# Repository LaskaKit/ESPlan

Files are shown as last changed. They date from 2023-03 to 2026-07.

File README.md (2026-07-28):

# ESPlan v2.1

**Read this in other languages: [Čeština](README_CZ)**

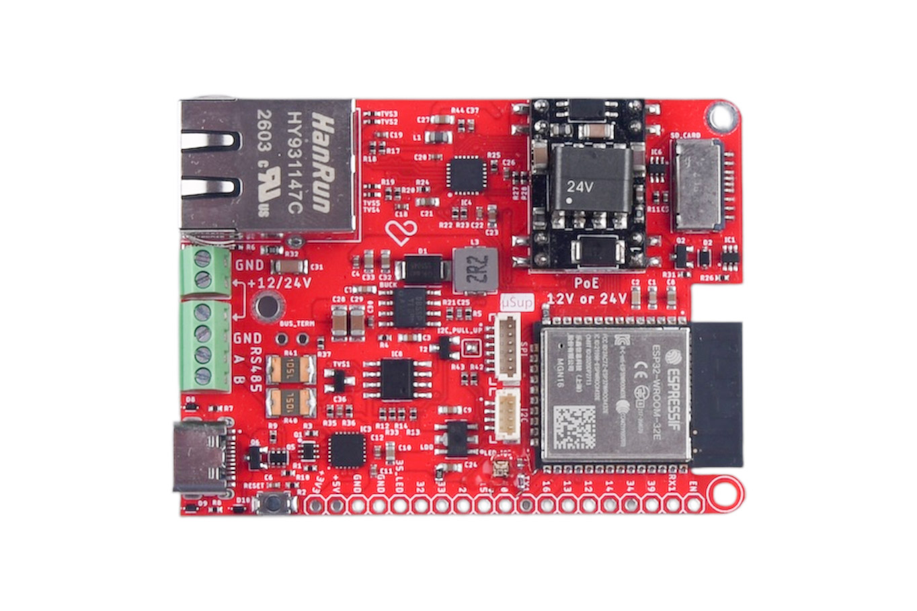
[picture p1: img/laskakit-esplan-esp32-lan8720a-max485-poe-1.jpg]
ESPlan


**LaskaKit ESPlan** is an industrial-grade ESP32 development board built around the **ESP32-WROOM-32E** module. It combines wired **Ethernet (LAN8720A)**, an **RS485** bus, **Wi-Fi + Bluetooth**, and **three independent ways to power the board** – including optional **PoE**. It is designed for industrial automation, IoT gateways, home automation (Home Assistant, ESPHome) and remote sensor nodes where reliable wired connectivity without dependence on Wi-Fi is required.

Designed and manufactured in the Czech Republic 🇨🇿

Product page: <https://www.laskakit.cz/laskakit-esplan-esp32-lan8720a-max485-poe/>

---

## ⚡ Power – three options

ESPlan v2.1 supports three power sources that can be combined freely. The source with the **highest voltage is always active**.

| Source | Input voltage | Path to the board | Typical use |
| --- | --- | --- | --- |
| **USB-C** | 5 V | direct to the 5 V rail | development, programming |
| **Screw terminal (+12/24 V, GND)** | **7–40 V DC** (12 or 24 V recommended) | step-down **LMR14050** (up to 5 A) → 5 V → LDO **XC6220** → 3.3 V | industrial PSU, DIN rail |
| **PoE (Power over Ethernet)** | via optional **SDaPo DP9900M** module (12 V or 24 V variant, **sold separately**) | PoE module output → same buck converter as the terminal | power straight from the LAN cable |

> **PoE note:** We recommend the **24 V** variant of the DP9900M – it better matches the converter input range and gives higher efficiency. The module meets **IEEE 802.3af** (up to 12.95 W), is galvanically isolated, and works with any PoE switch or injector.

The whole power chain is protected: terminal inputs are fused with a polyfuse, and the RS485 bus has TVS diodes (PSM712) and a polyfuse (MF-MSMF010-2) against overvoltage and shorts from the external line.

See annotated diagrams in [`img/power/`](img/power) for each option.

---

## 🔌 RS485 – wiring & terminal voltage

The RS485 terminal has **four pins: 12/24 V IN/OUT, GND, A, B**.

- **A and B are NOT power pins** – they carry the differential *data* signal from the **WS3081** transceiver. At idle the A−B difference is ~0 V; while transmitting, |A−B| is roughly **1.5–3 V** under load (per the RS485 standard the driver outputs ≥1.5 V differential, receivers detect ±200 mV, common-mode range −7 V to +12 V). **There is no usable supply voltage on A/B.**
- **Powering a remote RS485 device:** the terminal block also brings out **12/24 V IN/OUT**, so the same voltage you use to power the ESPlan (12 or 24 V) can be looped out to power a field sensor over the same run. If your sensor needs a different voltage (e.g. 5 V), use a local regulator at the sensor.
- **Bus wiring:** connect **A↔A, B↔B, GND↔GND**. At the end of a long run enable the on-board **120 Ω** termination with the **BUS_TERM** jumper – no external terminator needed.

---

## 🌐 Connectivity & interfaces

- **Ethernet** – LAN8720A PHY (Fast Ethernet 10/100 Mbps), HanRun RJ45 with integrated magnetics and status LEDs.
- **RS485** – WS3081 transceiver with TVS protection, screw terminal (12/24 V IN/OUT, GND, A, B), on-board 120 Ω termination via the `BUS_TERM` jumper.
- **Wi-Fi + Bluetooth** – built into the ESP32-WROOM-32E (2.4 GHz Wi-Fi 802.11 b/g/n, Bluetooth 4.2 / BLE).
- **microSD card** – slot over SPI with card-detect.
- **I²C connector** – dedicated 4-pin connector (3.3V, GND, SCL, SDA) with pull-ups for sensors, displays, etc.
- **SPI connector** – dedicated 6-pin connector (3.3V, GND, MOSI, MISO, SCK, CS).
- **GPIO header** – all free ESP32 pins broken out on a populated header.

---

## 📍 Pinout (v2.1)

| Function | GPIO |
| --- | --- |
| **I²C** SDA / SCL | IO33 / IO32 |
| **SPI** MISO / MOSI / CLK / CS | IO12 / IO13 / IO14 / IO15 |
| **microSD** MISO / MOSI / CLK / CS / CD | IO12 / IO13 / IO14 / IO2 / IO34 |
| **Ethernet** MDC / MDIO / NRST / CLK | IO23 / IO18 / IO5 / GPIO17 (out) |
| **User LED** (SK6812) | IO0 |
| Input-only pins | IO34, IO35, IO39 |

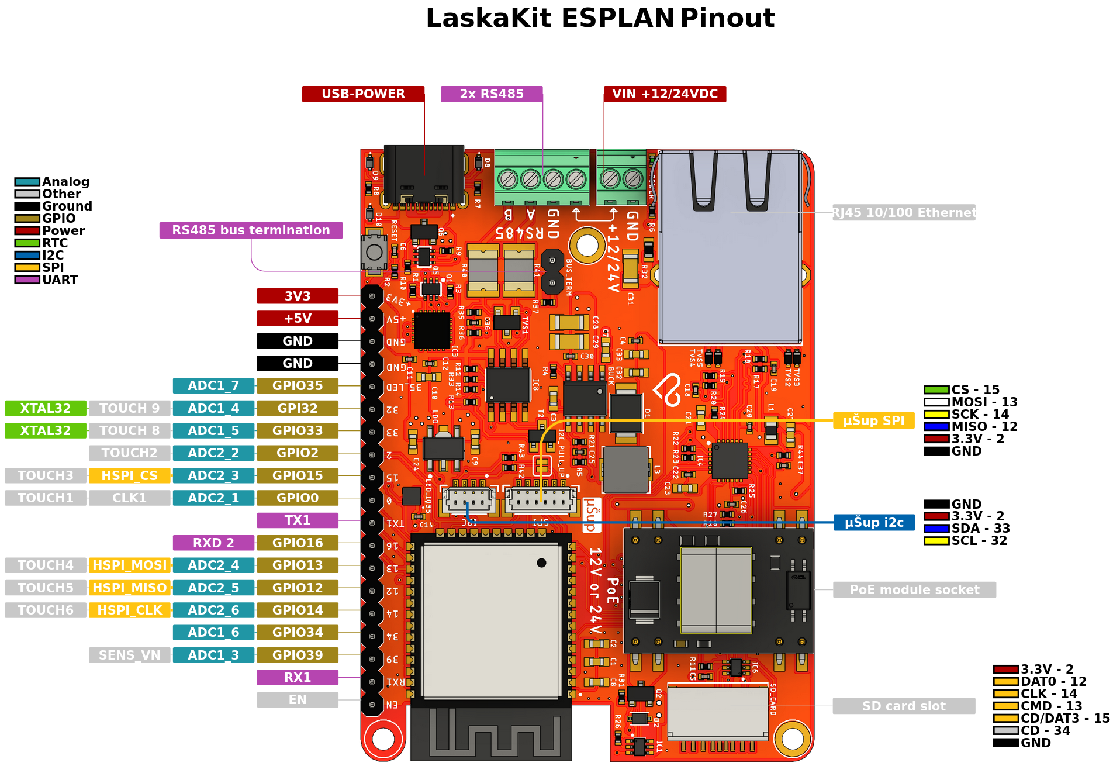
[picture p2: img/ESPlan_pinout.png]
ESPlan pinout


### Controls & LED

- **RESET** button – resets the ESP32.
- **IO0 / BOOT** button – enter firmware upload mode (RESET + IO0).
- **Status LED** (SK6812) on IO0 – programmable user LED.

> **Ethernet init (Arduino core 2.x):** the LAN8720A clock is on GPIO17. A known-good call is:
> ```cpp
> ETH.begin(0, -1, 23, 18, ETH_PHY_LAN8720, ETH_CLOCK_GPIO17_OUT);
> ```
> On newer cores use the named-enum signature, e.g. 
> ```cpp
> ETH.begin(ETH_PHY_LAN8720, ETH_ADDR, ETH_MDC_PIN, ETH_MDIO_PIN, ETH_POWER_PIN, ETH_CLOCK_GPIO17_OUT);
> ```
>
> **I²C init:**
> ```cpp
> Wire.begin(33, 32);
> ```
---

## 📐 Specifications

| | |
| --- | --- |
| **MCU** | ESP32-WROOM-32E (Xtensa LX6 dual-core 240 MHz, 4 MB Flash, Wi-Fi + BT) |
| **Ethernet PHY** | LAN8720A-CP, Fast Ethernet 10/100 Mbps |
| **RS485** | WS3081, half-duplex, TVS protection, optional 120 Ω termination |
| **Power – USB-C** | 5 V |
| **Power – terminal** | 7–40 V DC (12 or 24 V recommended) |
| **Power – PoE** | IEEE 802.3af via DP9900M module (12 V or 24 V variant, sold separately) |
| **Internal rails** | 5 V (buck LMR14050, up to 5 A) → 3.3 V (LDO XC6220) |
| **microSD** | SPI, connector with card detect |
| **Programming** | USB-C with on-board USB-UART bridge (auto-boot), RESET + BOOT buttons |
| **Compatibility** | Arduino IDE, ESP-IDF, ESPHome, Tasmota, MicroPython |

---

## 📦 Package contents

- 1× LaskaKit ESPlan v2.1

The PoE module (SDaPo DP9900M) and the 3D-printed enclosure are **not included** – ordered separately.

---

## 🖨️ 3D-printed enclosure

STL/3MF files for the enclosure are in the [`3D`](3D) folder.

---

## License & support

Open-source hardware by LaskaKit. Questions, issues and pull requests are welcome via the [Issues](../../issues) tab.

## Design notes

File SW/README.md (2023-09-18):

# How to make display work

1. Download [CH343SER.EXE](http://www.wch-ic.com/search?t=all&q=CH9102) and install it.

2. Connect ESPlan to your PC.

3. Open Device Manager (Start → Control Panel → Hardware and Sound → Device Manager) and find COM port number.

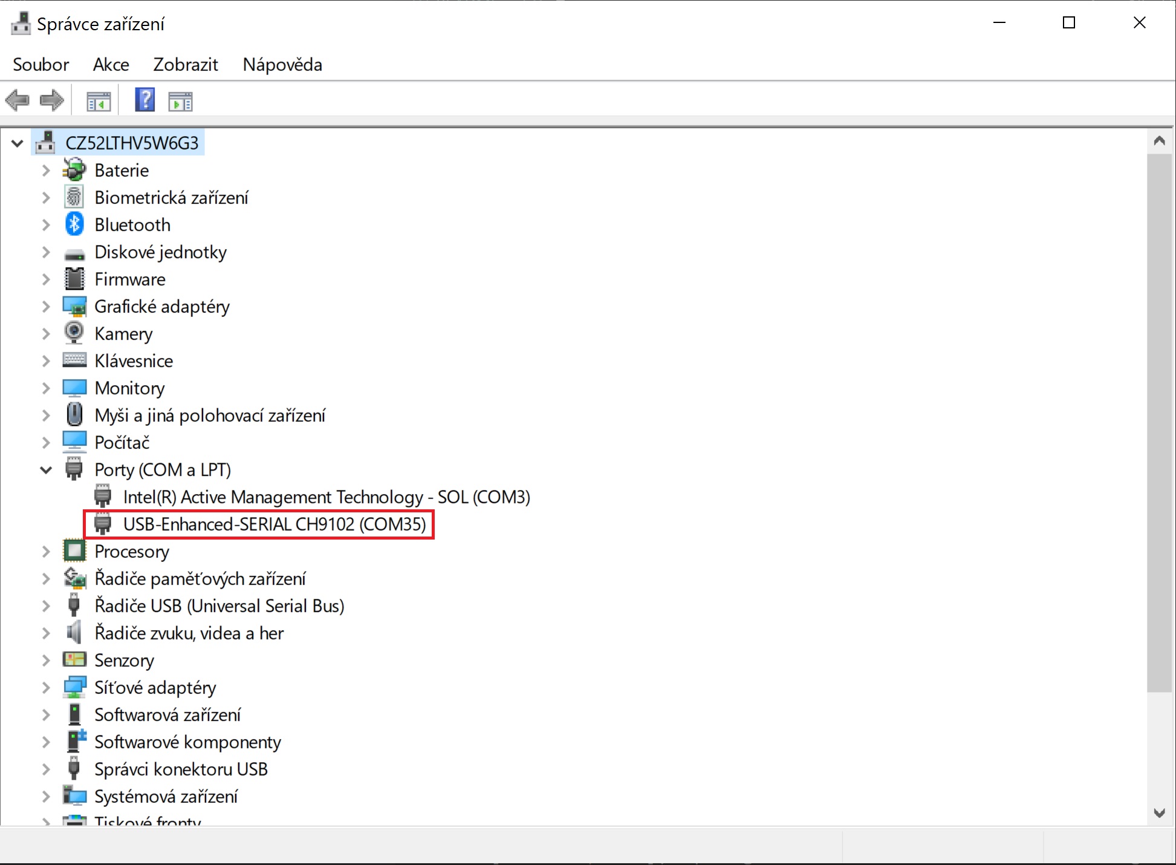
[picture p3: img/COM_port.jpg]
COM_port
    

## Arduino IDE
1. Download Github repository and look for project you want to try in [SW](../SW) folder.
2. Open example with Arduino IDE and set appropriate COM port and board type.
   
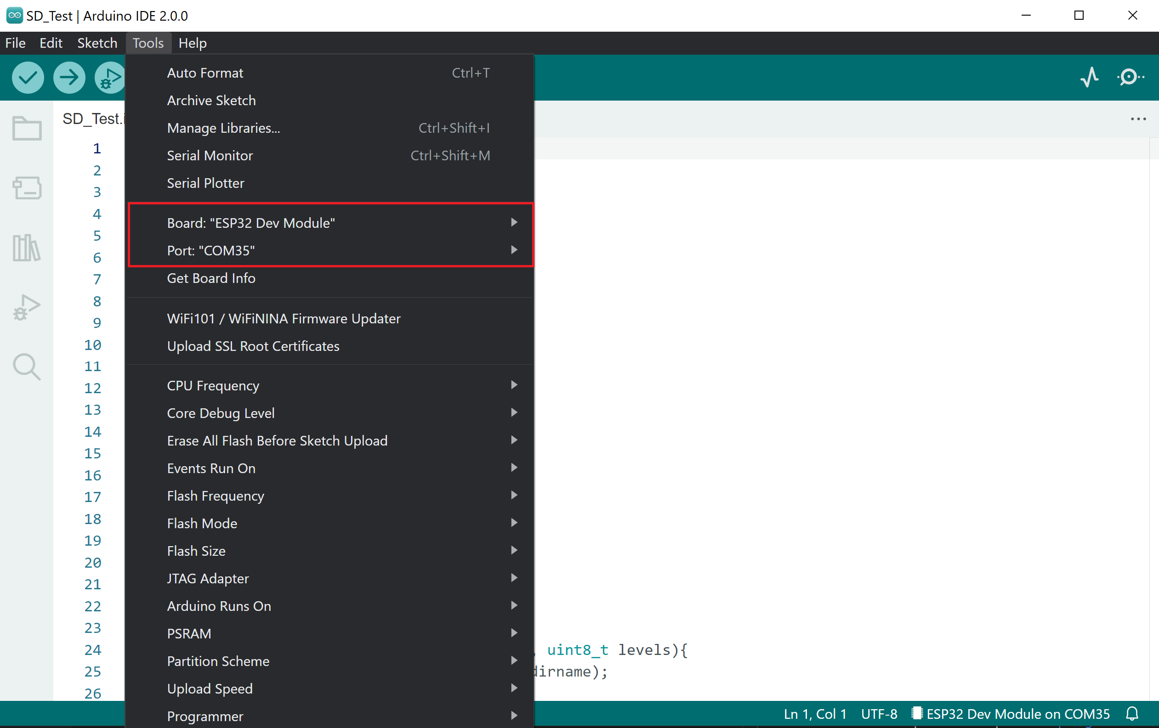
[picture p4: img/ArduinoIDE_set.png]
ArduinoIDE_set
    

3. Download necessary libraries.
4. Upload the code.

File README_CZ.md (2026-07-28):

# ESPlan v2.1

**Jiné jazyky: [English](README.md)**

ESPlan

**LaskaKit ESPlan** je průmyslová vývojová deska postavená na modulu **ESP32-WROOM-32E**. Kombinuje drátový **Ethernet (LAN8720A)**, sběrnici **RS485**, **Wi-Fi + Bluetooth** a **tři nezávislé způsoby napájení** – včetně volitelného **PoE**. Deska je určena pro průmyslovou automatizaci, IoT brány, domácí automatizaci (Home Assistant, ESPHome) i vzdálené senzorové uzly, kde je potřeba spolehlivá kabelová konektivita bez závislosti na Wi-Fi.

Navrženo a vyrobeno v ČR 🇨🇿

Stránka produktu: <https://www.laskakit.cz/laskakit-esplan-esp32-lan8720a-max485-poe/>

---

## ⚡ Napájení – tři možnosti

ESPlan v2.1 podporuje tři zdroje napájení, které lze libovolně kombinovat. Vždy je aktivní ten s **nejvyšším napětím**.

| Zdroj | Vstupní napětí | Cesta na desku | Typické použití |
| --- | --- | --- | --- |
| **USB-C** | 5 V | přímo na 5V větev | vývoj, programování |
| **Šroubovací svorkovnice (+12/24 V, GND)** | **7–40 V DC** (doporučeno 12 nebo 24 V) | step-down **LMR14050** (až 5 A) → 5 V → LDO **XC6220** → 3,3 V | průmyslový zdroj, DIN lišta |
| **PoE (Power over Ethernet)** | přes volitelný modul **SDaPo DP9900M** (varianta 12 V nebo 24 V, **kupuje se zvlášť**) | výstup PoE modulu → stejný buck měnič jako svorkovnice | napájení přímo z LAN kabelu |

> **Poznámka k PoE:** Doporučujeme variantu DP9900M **24 V** – lépe odpovídá vstupnímu rozsahu měniče a má vyšší účinnost. Modul splňuje **IEEE 802.3af** (až 12,95 W), má galvanické oddělení a pracuje s libovolným PoE switchem nebo injektorem.

Celý napájecí řetězec je chráněn: svorkovnicové vstupy jsou jištěny polyfuse, na RS485 sběrnici jsou TVS diody (PSM712) a polyfuse (MF-MSMF010-2) proti přepětí a zkratu z externího vedení.

Anotované obrázky ke každé možnosti najdeš v [`img/power/`](img/power).

---

## 🔌 RS485 – zapojení a napětí na svorkách

Svorkovnice RS485 má **tři vývody: GND, A, B**.

- **A a B nejsou napájecí piny** – nesou diferenciální *datový* signál z transceiveru **WS3081**. V klidu je rozdíl A−B přibližně 0 V; při vysílání je |A−B| zhruba **1,5–3 V** pod zátěží (dle standardu RS485 vysílač generuje ≥1,5 V diferenciálně, přijímač detekuje ±200 mV, common-mode rozsah −7 V až +12 V). **Žádné použitelné napájení na A/B není.**
- **Napájení připojeného RS485 zařízení:** na svorkovnici je navíc vyvedeno **12/24 V IN/OUT**, takže stejné napětí, kterým napájíš ESPlan (12 nebo 24 V), můžeš vyvést ven a napájet jím vzdálené čidlo po stejném vedení. Pokud čidlo potřebuje jiné napětí (např. 5 V), použij u čidla vlastní měnič.
- **Zapojení sběrnice:** propoj **A↔A, B↔B, GND↔GND**. Na konci dlouhého vedení zapni zakončovací odpor **120 Ω** jumperem **BUS_TERM** – externí terminátor není potřeba.

---

## 🌐 Konektivita a rozhraní

- **Ethernet** – PHY LAN8720A (Fast Ethernet 10/100 Mbps), konektor RJ45 HanRun s integrovanými transformátory a stavovými LED.
- **RS485** – transceiver WS3081 s TVS ochranou, šroubovací svorkovnice (GND, A, B), zakončení 120 Ω přes jumper `BUS_TERM`.
- **Wi-Fi + Bluetooth** – vestavěné v ESP32-WROOM-32E (2,4 GHz Wi-Fi 802.11 b/g/n, Bluetooth 4.2 / BLE).
- **microSD karta** – slot přes SPI s detekcí karty.
- **I²C konektor** – dedikovaný 4pinový konektor (3,3 V, GND, SCL, SDA) s pull-up rezistory pro senzory, displeje apod.
- **µSup konektor** – SPI konektor pro volitelný modul superkondenzátoru (µSup) pro krátké zálohování při výpadku napájení.
- **GPIO header** – všechny volné piny ESP32 vyvedeny na osazený header.

---

## 📍 Pinout (v2.1)

| Funkce | GPIO |
| --- | --- |
| **I²C** SDA / SCL | IO33 / IO32 |
| **SPI** MISO / MOSI / CLK / CS | IO12 / IO13 / IO14 / IO15 |
| **microSD** MISO / MOSI / CLK / CS / CD | IO12 / IO13 / IO14 / IO2 / IO34 |
| **Ethernet** MDC / MDIO / NRST / CLK | IO23 / IO18 / IO5 / GPIO17 (out) |
| **Uživatelská LED** (SK6812) | IO0 |
| Pouze vstupní piny | IO34, IO35, IO39 |

ESPlan pinout

### Ovládací prvky a LED

- Tlačítko **RESET** – reset ESP32.
- Tlačítko **IO0 / BOOT** – vstup do režimu nahrávání firmware (RESET + IO0).
- **Stavová LED** (SK6812) na IO0 – programovatelná uživatelská LED.

> **Inicializace Ethernetu (Arduino core 2.x):** hodiny LAN8720A jsou na GPIO17. Ověřené volání:
> ```cpp
> ETH.begin(0, -1, 23, 18, ETH_PHY_LAN8720, ETH_CLOCK_GPIO17_OUT);
> ```
> Na novějších core použij signaturu s pojmenovanými enumy, např. `ETH.begin(ETH_PHY_LAN8720, ETH_ADDR, ETH_MDC_PIN, ETH_MDIO_PIN, ETH_POWER_PIN, ETH_CLOCK_GPIO17_OUT);`
>
> **Inicializace I²C:** `Wire.begin(33, 32);`

---

## 📐 Specifikace

| | |
| --- | --- |
| **MCU** | ESP32-WROOM-32E (Xtensa LX6 dual-core 240 MHz, 4 MB Flash, Wi-Fi + BT) |
| **Ethernet PHY** | LAN8720A-CP, Fast Ethernet 10/100 Mbps |
| **RS485** | WS3081, half-duplex, TVS ochrana, volitelné zakončení 120 Ω |
| **Napájení – USB-C** | 5 V |
| **Napájení – svorkovnice** | 7–40 V DC (doporučeno 12 nebo 24 V) |
| **Napájení – PoE** | IEEE 802.3af přes modul DP9900M (varianta 12 V nebo 24 V, kupuje se zvlášť) |
| **Interní napájecí větve** | 5 V (buck LMR14050, až 5 A) → 3,3 V (LDO XC6220) |
| **microSD** | SPI, konektor s detekcí karty |
| **Programování** | USB-C s on-board USB-UART převodníkem (auto-boot), tlačítka RESET + BOOT |
| **Kompatibilita** | Arduino IDE, ESP-IDF, ESPHome, Tasmota, MicroPython |

---

## 📦 Obsah balení

- 1× LaskaKit ESPlan v2.1

PoE modul (SDaPo DP9900M) a 3D tištěná krabička **nejsou součástí balení** – objednávají se samostatně.

---

## 🖨️ 3D tištěná krabička

STL/3MF soubory krabičky najdeš ve složce [`3D`](3D).

---

## Licence a podpora

Open-source hardware od LaskaKit. Dotazy, chyby i pull requesty vítáme přes záložku [Issues](../../issues).

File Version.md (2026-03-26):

### Version 2.1
- LED IO changed from IO35 to IO0
- Added pull-down on IO12
#### Version 2.0
- Smaller board
- New power part, new PoE
- Power to RS485 from PoE
#### Version 1.1
- Added jumper for diskonecting CAN Bus 120Ihm resistor | Přidan jumper pro odpojení 120 Ohm odporu pro CAN sběrnici.
#### Version 1.0
- Initial | Počáteční

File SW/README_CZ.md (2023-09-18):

# Jak pracovat s displejem

1. Stáhnout [CH343SER.EXE](http://www.wch-ic.com/search?t=all&q=CH9102) a nainstalovat. Návod i na našem [blogu](https://blog.laskakit.cz/instalace-ovladace-prevodniku-usb-na-uart-ch340/).

2. Zapojit ESPlan do PC.

3. Start – Systém – Správce zařízení (může být potřeba oprávnění správce) najít položku Porty (COM a LPT).

    COM_port

## Arduino IDE
1. Stáhnout Github repository a otevřít příklad, který chcete zkusit ze složky [SW](../SW).
2. Otevřít příklad pomocí Arduino IDE a nastavit správný COM port a typ desky.
   
    ArduinoIDE_set

3. Stáhnout nezbytné knihovny.
4. Nahrát kód.

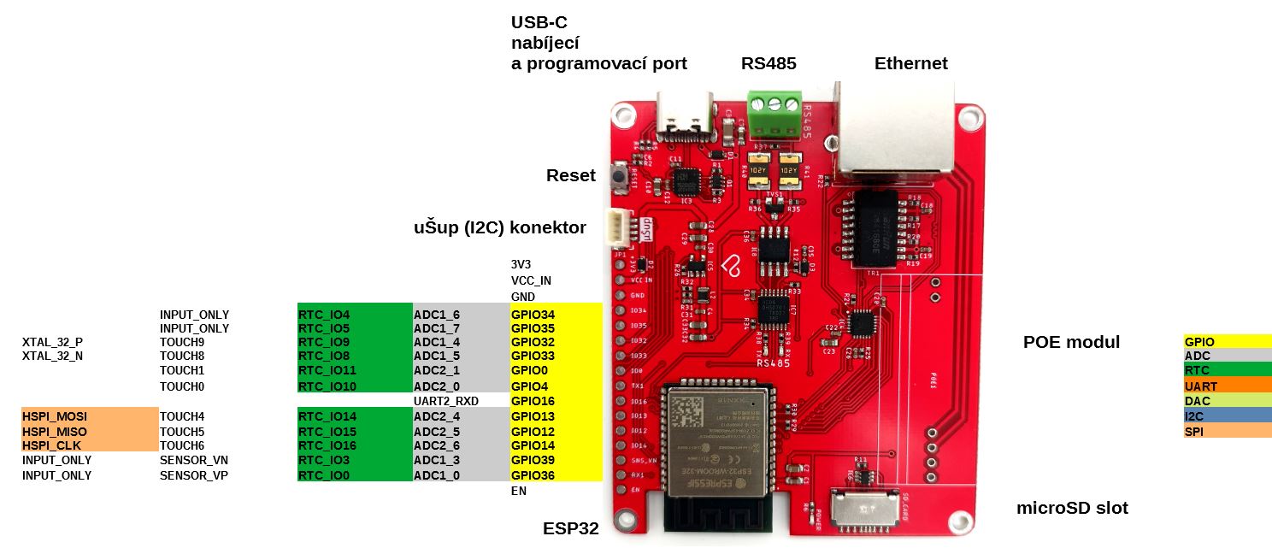
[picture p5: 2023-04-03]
img/ESPlan_pinout.JPG

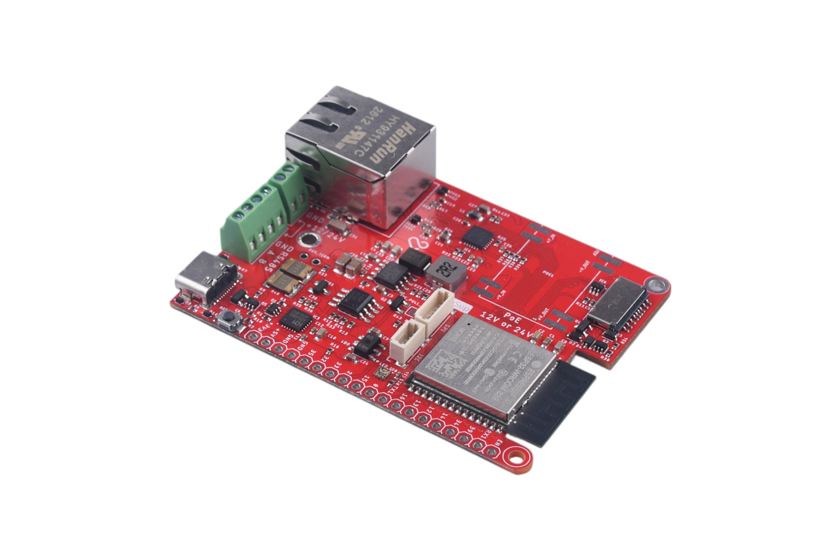
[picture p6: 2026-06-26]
img/laskakit-esplan-esp32-lan8720a-max485-3.jpg

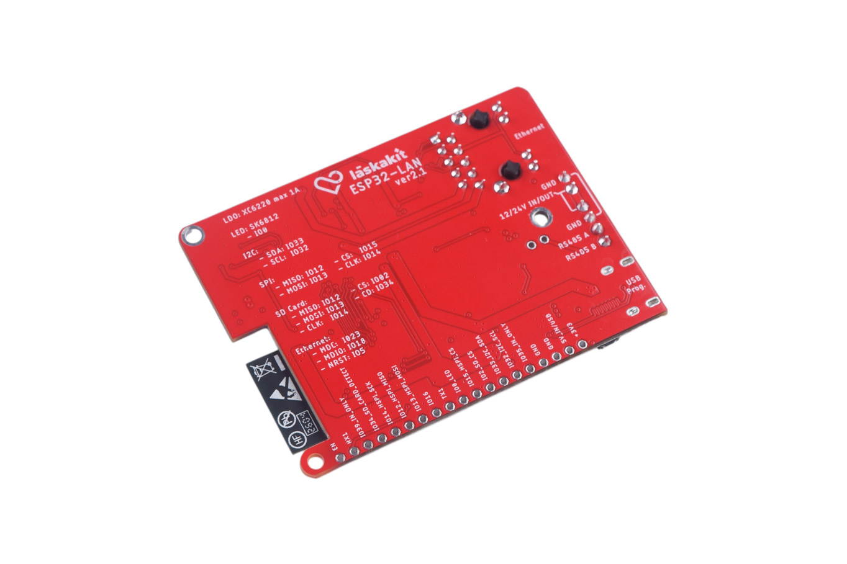
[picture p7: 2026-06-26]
img/laskakit-esplan-esp32-lan8720a-max485-poe-2.jpg

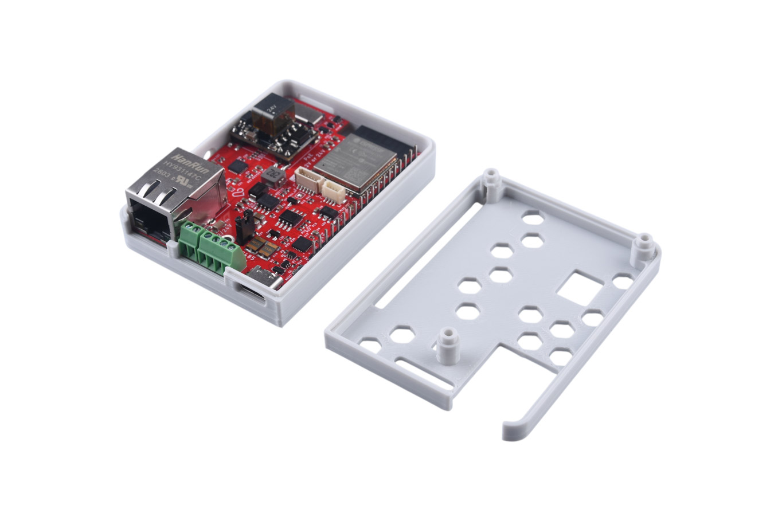
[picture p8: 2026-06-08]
img/laskakit-krabicka-pro-laskakit-esplan-v2-1.jpg

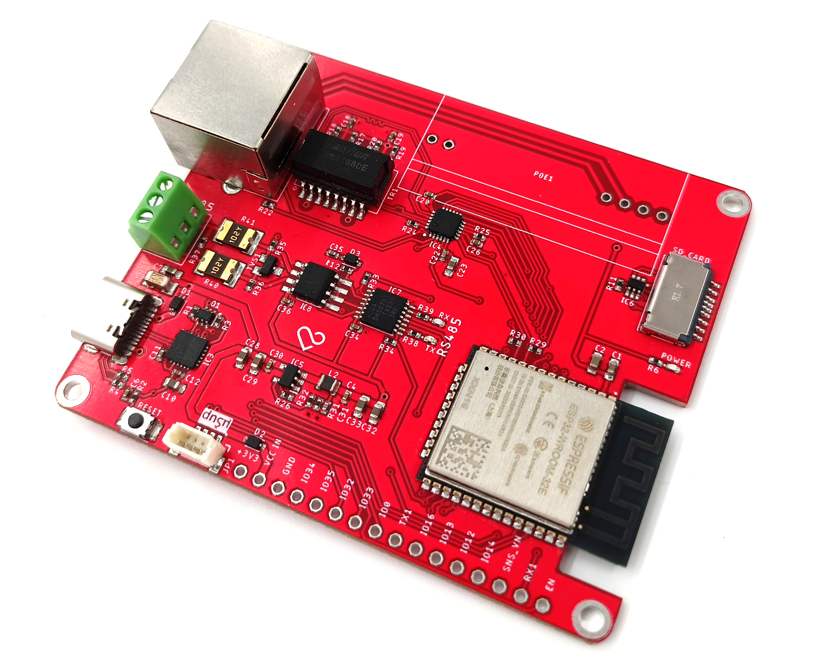
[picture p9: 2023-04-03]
img/ESPlan (2).jpg

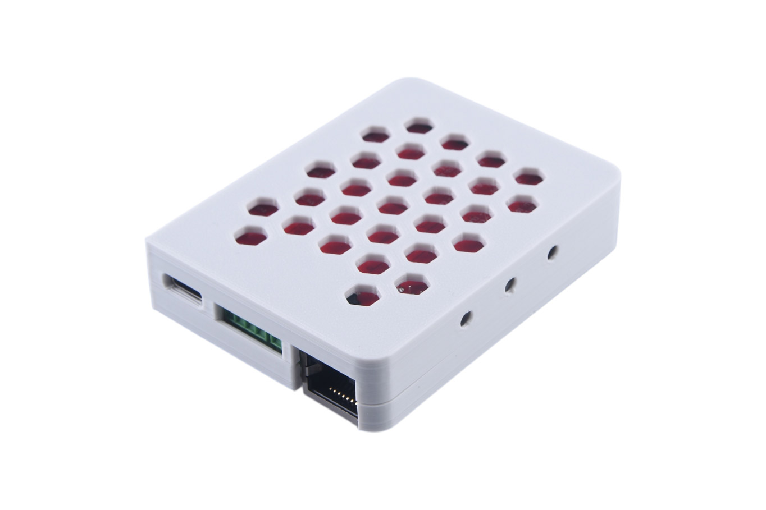
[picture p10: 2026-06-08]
img/laskakit-krabicka-pro-laskakit-esplan-v2-2.jpg

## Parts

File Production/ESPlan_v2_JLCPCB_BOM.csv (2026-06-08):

Comment | Designator | Footprint | LCSC Part #
100nF | C1 C7 | C0603
10k | R1 R2 R3 R11 R16 R25 R27 R28 R29 R30 R35 R36 R44 | R0402
100nF | C5 C6 C14 C36 C37 | C0402
TS1088R02026 | RESET | TS1088R02026 | C455280
MMDT3904 | Q1 | SC70-6 | C268586
47uF | C2 | C0603
uSup | J3 | 1X04_1MM_RA_VERT | C371588
ESP32-WROOM-32E | IC2 | ESP32WROOM32E | C701343
22uF | C8 C10 C27 C32 C33 | C0603
100n | C4 C11 C12 C18 C19 C20 C26 | C0402
CH9102F | IC3 | QFN24-4X4
LAN8720A-CP-ABC | IC4 | QFN50P400X400X100-25N | C510876
10uF | C21 | C0603
49.9 | R17 R18 R19 R20 | R0402
10n | C22 | C0402
2.2uF | C23 | C0603
YI201209U601-2R0T | L1 | L0805 | C2858468
1k | R22 R23 | R0402
12.1k | R24 | R0402
22uF/50V | C28 C29 | C1206 | C22367834
100n/50V | C30 | C0402
SMF05C | IC6 | SOT65P210X110-6N
WS3081 | IC8 | SO08 | C2691428
4.7k | R12 R13 R14 R33 R42 R43 | R0402
120 | R37 | R0402
PSM712-LF-T7 | TVS1 | SOT23 | C32677
MF-MSMF010-2 | R40 R41 | CT/CN1812 | C12430
2.4k | R6 | R0402
16-213/GHC-YR1S1/3T | POWER | CHIPLED_0402
TF-123-ARP9H17 | SD_CARD | SD_CARD_M | C2982548
TERMINAL_2_54_2P | T1 | TERMINAL_2_54_2P | C918120
10uF/16 | C9 | C0603
10uF/10V | C24 | C0603 | C19666
XC6220B331PR-G | LDO | XC6220B331PRG
5.1k | R7 R8 | R0402
USB-C_GT-USB-7010B | J2 | G-SWITCH_GT-USB-7010B | C2837092
LESD5D5.0CT1G | D8 D9 D10 | LESD5D50CT1G
MMDT5401 | Q3 Q5 | SC70-6 | C54540
DMG2305UX | Q6 | MICRO3 | C144153
47k | R9 R10 | R0402
USUP_SPI_CONNECTOR_VERT | J4 | 1X06_1MM_RA_VERT | C145963
2.2uH | L3 | L5.4X5.2 | C351096
LMR14050DDAR | BUCK | SO08-EPAD | C155484
20k | R4 | R0402
8.2nF | C3 | C0603
68k | R5 | R0402
12k | R21 | R0402
330pF | C25 | C0402
SS1045-SMB | D1 | SMB | C2903947
BZT52C15S | D2 | SOD323-R
0402WGF1004TCE | TVS2 TVS3 TVS4 TVS5 | SOD523 | C5185906
1n/2KV | C31 | C1206 | C23631
1M | R32 | R0603
HY931147C-RJ45 | J5 | HY931147C | C91754
S8050 | Q2 | SOT23-BEC
TERMINAL_2_54_4P | T3 | TERMINAL_2_54_4P | C918122
SK6812-EC20 | LED_IO0 | SK6812EC20
470 | R15 | R0402
SI2319 | Q4 | MICRO3 | C144153
100k | R34 R38 | R0402
1N4148 | D3 D4 | SOD323-R

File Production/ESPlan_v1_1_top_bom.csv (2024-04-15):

Comment | Designator | Footprint | LCSC Part #
1.1k | R32 | R0402
1N4148 | D3 | SOD323-R | C84063
1k | R22 | R0402
1uF | C7 | C0603
2.2uF | C23 | C0603
2.4k | R6 R38 R39 | R0402
4.7k | R33 R34 | R0402
4.99k | R31 | R0402 | C284594
5.1k | R4 R5 | R0402
10k | R1 R2 R3 R11 R25 R29 R30 R35 R36 | R0402
10n | C22 | C0402
12.1k | R24 | R0402
22p | C31 | C0402
22uF | C10 C28 C29 C32 C33 | C0603
33pF | C35 | C0402
47uF | C2 | C0603
49.9 | R17 R18 R19 R20 | R0402
56k | R12 | R0402
100k | R26 | R0402
100n | C4 C11 C12 C18 C19 C20 C26 C30 C34 | C0402
100nF | C1 | C0603
100nF | C6 C36 | C0402
100uF | C3 | C1206
120 | R37 | R0402
7404PW 118 | IC7 | TSSOP14 | C80000
BAT60B | D1 D2 D4 | SOD323-R
CH9102F | IC3 | QFN24-4X4
ESP32-WROOM-32E | IC2 | ESP32WROOM32E | C701343
GREEN | POWER RX | CHIPLED_0402
HR641680E | TR1 | ETH_TR
LAN8720A-CP-ABC | IC4 | QFN50P400X400X100-25N | C621419
MF-MSMF010-2 | R40 R41 | CT/CN1812 | C12430
MMDT3904 | Q1 | SC70-6 | C268586
MPL2016S2R2 | L2 | L2016 | C42215
ORANGE | TX | CHIPLED_0402
PSM712-LF-T7 | TVS1 | SOT23 | C32677
SMF05C | IC6 | SOT65P210X110-6N | C558425
SY8089AAAC | IC5 | SOT-23-5 | C78988
TF-123-ARP9H17 | SD_CARD | SD_CARD_M | C2982548
TS1088R02026 | RESET | TS1088R02026 | C455280
USB-C_2-16PIN | J4 | USBC_USB-C-16P-5 | C2837092
WS3081 | IC8 | SO08 | C2691428
uSup | J3 | 1X04_1MM_RA_VERT | C371588
1k | R23 | R0402
1n/2KV | C15 | C1206 | C23631
10k | R27 R28 R42 R43 | R0402
10n/100V | C13 C14 C16 C17 | C0603
10uF | C21 | C0603
22uF | C27 | C0603
75 | R13 R14 R15 R16 | R0603 | C112309
100nF | C5 | C0402
YI201209U601-2R0T | L1 | L0805 | C2858468
TERMINAL_2_54_3P | RS485 | TERMINAL_2_54_3P | C68305
R-RJ45R08P-C000 | LAN | R-RJ45R08P-C000 | C386757

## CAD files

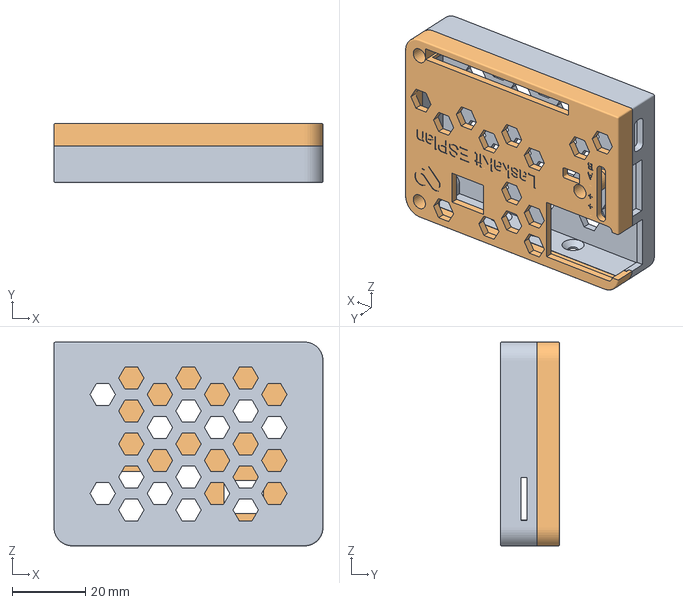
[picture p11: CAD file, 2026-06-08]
3D/ESPlan_case_V2.3mf
73.4 x 16.2 x 55.6 mm

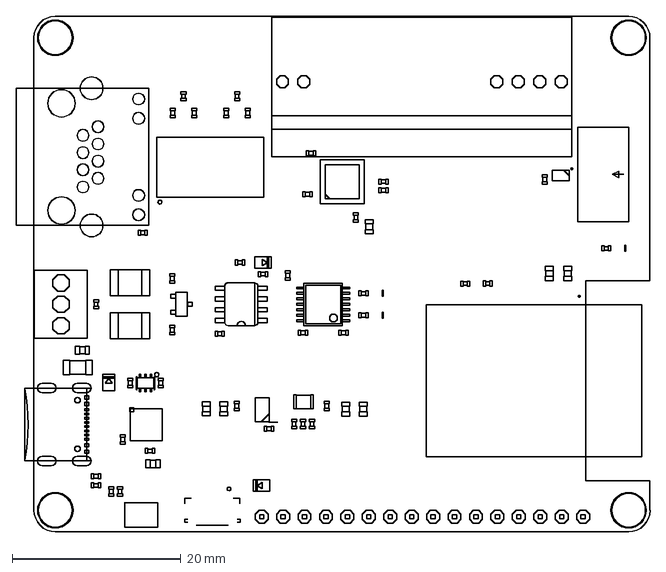
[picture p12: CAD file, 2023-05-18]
HW/ESPlan v1.dxf
75.1 x 61.1 mm

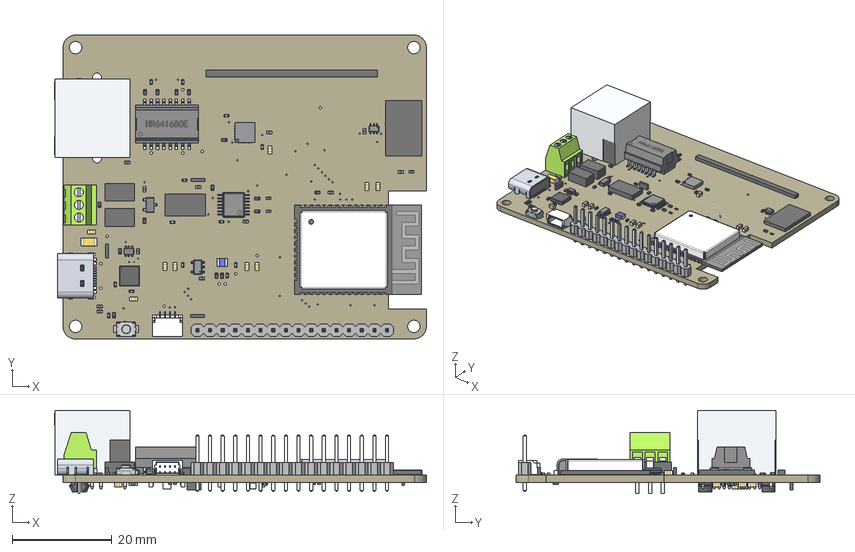
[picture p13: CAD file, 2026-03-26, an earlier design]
3D/old/ESPlan.step
74.7 x 61.1 x 16.7 mm
Board
Gehäuse
Kontaktfläche x 2
LASKAKIT_HEART_4MM
USUP_4MM_SILKSCREEN
1X04_1MM_RA
1X16
USBC_USB-C-16P-5
SC70-6
SOT23
QFN24-4X4
ThermalPin
PinsArrayLR
PinsArrayTB
PinsArrayLR (1)
TSSOP14
DP1435
PinsArrayL
PinsArrayR
TS1088R02026
SO08
ETH_TR
term1
term2
RJ45_LED
SD_CARD_M
Housing
PlasticBody
ESP32WROOM32E
Pin1 x 15
Pin2 x 15
CeramicBody x 15
CHIPLED_0402 x 3
2,5-PAD x 4
SOD323-R x 4
C0603 x 15
C1206 x 2
R0402 x 32
R0603 x 4
CT/CN1812 x 2

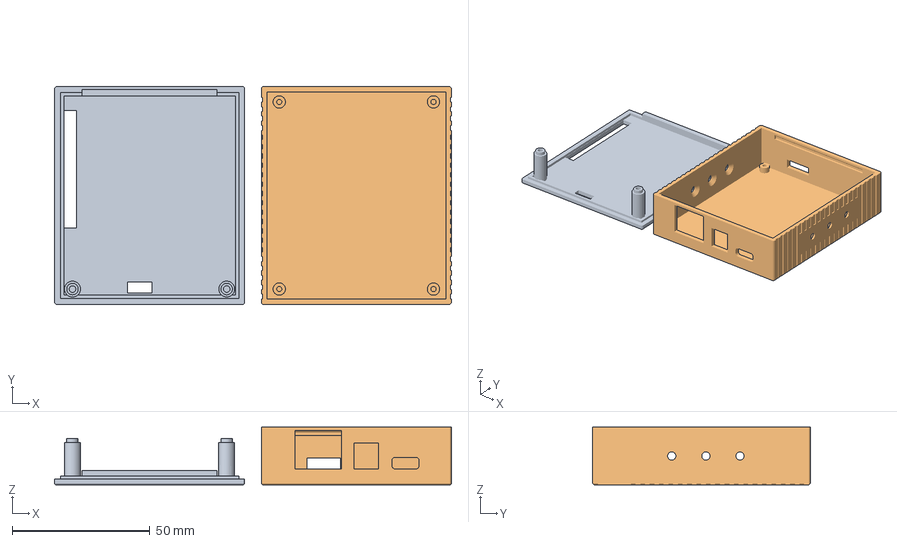
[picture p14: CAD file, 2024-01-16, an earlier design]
3D/ESPlan_case.3mf
144.2 x 79.0 x 21.0 mm
Bottom_cover v12
Top_cover

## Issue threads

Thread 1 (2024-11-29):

Ethernet not getting IP adress - ESPlan nedostavá ip adresu

ondrej1808, 2024-11-29:
Dobrý den,

mám problém s Ethernetem na desce ESPlan 1.1:

Měl jsem na novém ESPlan 1.1 jednoduchý program, který četl digitální vstupy a ty zobrazoval na modbus serveru.
Po určité době vývoje tohoto projektu se při nahrání nového kódu stane, že přestane dostavát ip adresu.
Resp.: když si do sériového výstupu vypíšu ip adresu tak dostanu 0.0.0.0, což znamená, že buďto neproběhla
žádná komunikace s routerem nebo ESPlan ani o adresu nezažádalo.

Zkoušel jsem použít novou desku, ta však zhruba po měsíci, když jsem pouze odpojil a připojil síťový kabel, tak začala vykazovat stejný problém.

Dále jsem zkoušel jednoduchý kód, který se má připojit k síti a vypsat ip adresu, opět neúspěšně.
Nemyslím si že by byl problém na straně routeru a nastevní sítě, jelikož úplně nová deska fungovala s posledním kódem staré desky.

Testovací kód pro připojení k WiFi (PlatformIO, framework arduino):

main.cpp:
```
#include <Arduino.h>
#include <ETH.h>
#include <WiFi.h>

#define ETH_POWER_PIN -1
#define ETH_ADDR 0
#define ETH_MDC_PIN 23
#define ETH_MDIO_PIN 18
#define ETH_NRST_PIN 5

bool eth_connected = false;

void WiFiEvent(WiFiEvent_t event)
{
  switch (event)
  {
  case ARDUINO_EVENT_ETH_START:
    Serial.println("ETH Started");
    // set eth hostname here
    ETH.setHostname("UCS2.0");
    break;
  case ARDUINO_EVENT_ETH_CONNECTED:
    Serial.println("ETH Connected");
    break;
  case ARDUINO_EVENT_ETH_GOT_IP:
    Serial.print("ETH MAC: ");
    Serial.print(ETH.macAddress());
    Serial.print(", IPv4: ");
    Serial.print(ETH.localIP());
    if (ETH.fullDuplex())
    {
      Serial.print(", FULL_DUPLEX");
    }
    Serial.print(", ");
    Serial.print(ETH.linkSpeed());
    Serial.println("Mbps");
    eth_connected = true;
    break;
  case ARDUINO_EVENT_ETH_DISCONNECTED:
    Serial.println("ETH Disconnected");
    eth_connected = false;
    break;
  case ARDUINO_EVENT_ETH_STOP:
    Serial.println("ETH Stopped");
    eth_connected = false;
    break;
  default:
    break;
  }
}

void setup()
{
  Serial.begin(115200);
  // For reseting LAN8720A
  pinMode(ETH_NRST_PIN, OUTPUT);
  digitalWrite(ETH_NRST_PIN, LOW);
  delay(500);
  digitalWrite(ETH_NRST_PIN, HIGH);

  WiFi.onEvent(WiFiEvent);

  ETH.begin(ETH_ADDR, ETH_POWER_PIN, ETH_MDC_PIN, ETH_MDIO_PIN, ETH_PHY_LAN8720, ETH_CLOCK_GPIO17_OUT);

  delay(2000);
  Serial.println("Ethernet status: " + ETH.localIP().toString() + " " + ETH.macAddress() + " " + ETH.linkSpeed() + "Mbps");
}

void loop()
{
  // put your main code here, to run repeatedly:
}
```

platformio.ini:
```
[env:esp32dev]
platform = espressif32
board = esp32dev
framework = arduino
monitor_speed = 115200
```

Výstup v sériovém monitoru:
```
rst:0xc (SW_CPU_RESET),boot:0x17 (SPI_FAST_FLASH_BOOT)
configsip: 0, SPIWP:0xee
clk_drv:0x00,q_drv:0x00,d_drv:0x00,cs0_drv:0x00,hd_drv:0x00,wp_drv:0x00
mode:DIO, clock div:2
load:0x3fff0030,len:1184
load:0x40078000,len:13232
load:0x40080400,len:3028
entry 0x400805e4
0
ETH Started
Ethernet status: 0.0.0.0 70:B8:F6:4C:62:53 10Mbps
ets Jul 29 2019 12:21:46
```

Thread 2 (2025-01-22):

3D files fail to load using Prusa Slicer

hamanbnl, 2025-01-22:
As described in the topic.
Prusa Slicer: Version 2.8.1+win64

Step file : "Invalid string position".
Unfortunately - nothing more.

3mf file: PrusaSlicer has encountered an error "Loading of a model file failed".
No details more.

Please correct the above files or post STL or OBJ files in right shape for importing.
Thanks in advance

hamanbnl, 2025-01-22:
Dobry večer,

Typická arogantní odpověď : “Pro mně funguje”.
Napsal jsem van verze, a tam je vidět, že používám windows. A ne Mac.
Ne napsali jste jakou verzi programu užíváte.

Ja mam problém a ne vy i prosím o vyřešení, protože jsem jisty ze nejsem
sám s tym problémem.

S pozdravem
Emil Krotki
+420 731 051 269

On Wed 22. 1. 2025 at 11:09, Konstantin Láska ***@***.***>
wrote:

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

Konstantin-G, 2025-01-22:
Dobrý den,
verze jsem napsal: 2.9.0.
na windows vám kolega psal, že zkoušel:
Dobrý den, soubory jsou v pořádku. Vyzkoušel jsem aktuální verzi souboru a v Prusa sliceru jsem jej bez problémů otevřel. Je spíše možné, že se soubor chybně stáhnul. Zkuste stáhnout celý projekt jako zip.

hamanbnl, 2025-01-22:
Dobry večer,

Našel jsem kde je problém. Odkaz ze stránek obchodu vede k GitHub. Tam jsou
dva soubory, stažení jejich rovné “save as” vede k chybě.

Je nezbytné využít “download raw file”. Tenhle funguje správně, ověřil jsem
na “3mf” a to pro mě stačí.
Dal bych na stránkách varováni pro lamerů jako ja.

Bohužel, mam už svůj projekt, ještě možna využiji vaši krytku, ale nezbytné
to není, uděláni krytky je 15 minut, no možná 30…

Doporučoval bych také tisk s využitím nehořlavého filamentu, ale to
zvládnu, a na stánkách obchodu varoval bych lidi o tom.

Moc dekuji, přeji hezký večer.

S pozdravem
Emil Krotki
+420 731 051 269

On Wed 22. 1. 2025 at 19:21, Konstantin Láska ***@***.***>
wrote:

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

Closed 2025-01-22.

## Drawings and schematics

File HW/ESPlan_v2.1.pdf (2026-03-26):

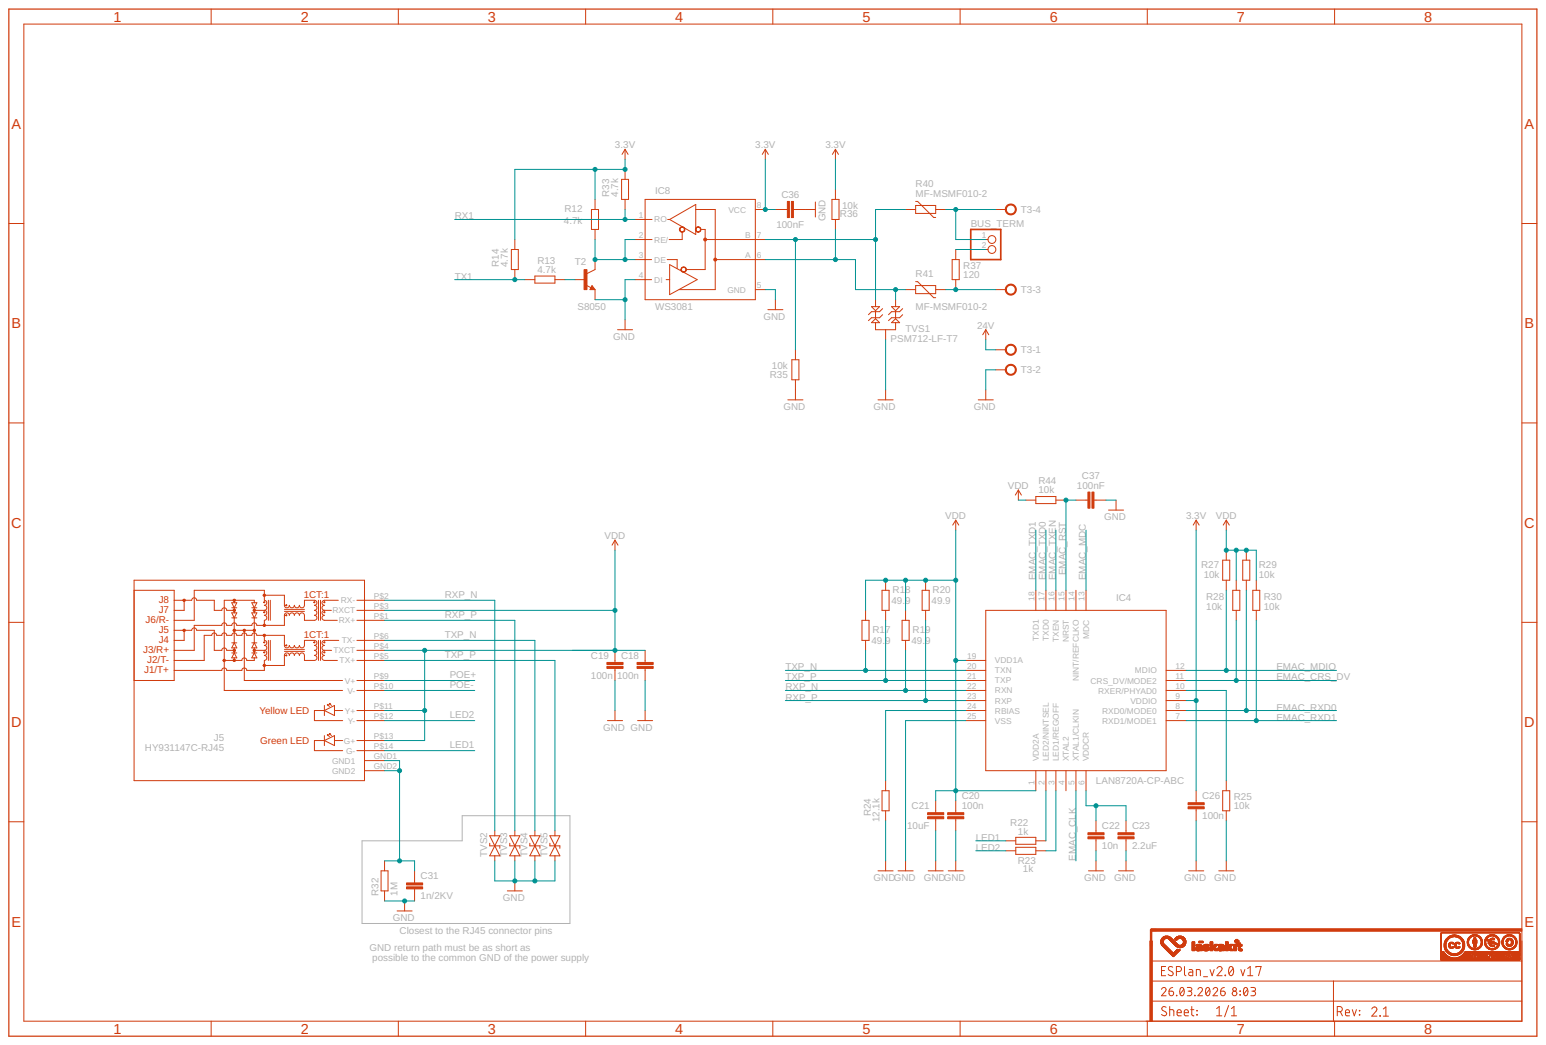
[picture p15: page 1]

GND
Closest to the RJ45 connector pins GND return path must be as short as possible to the common GND of the power supply

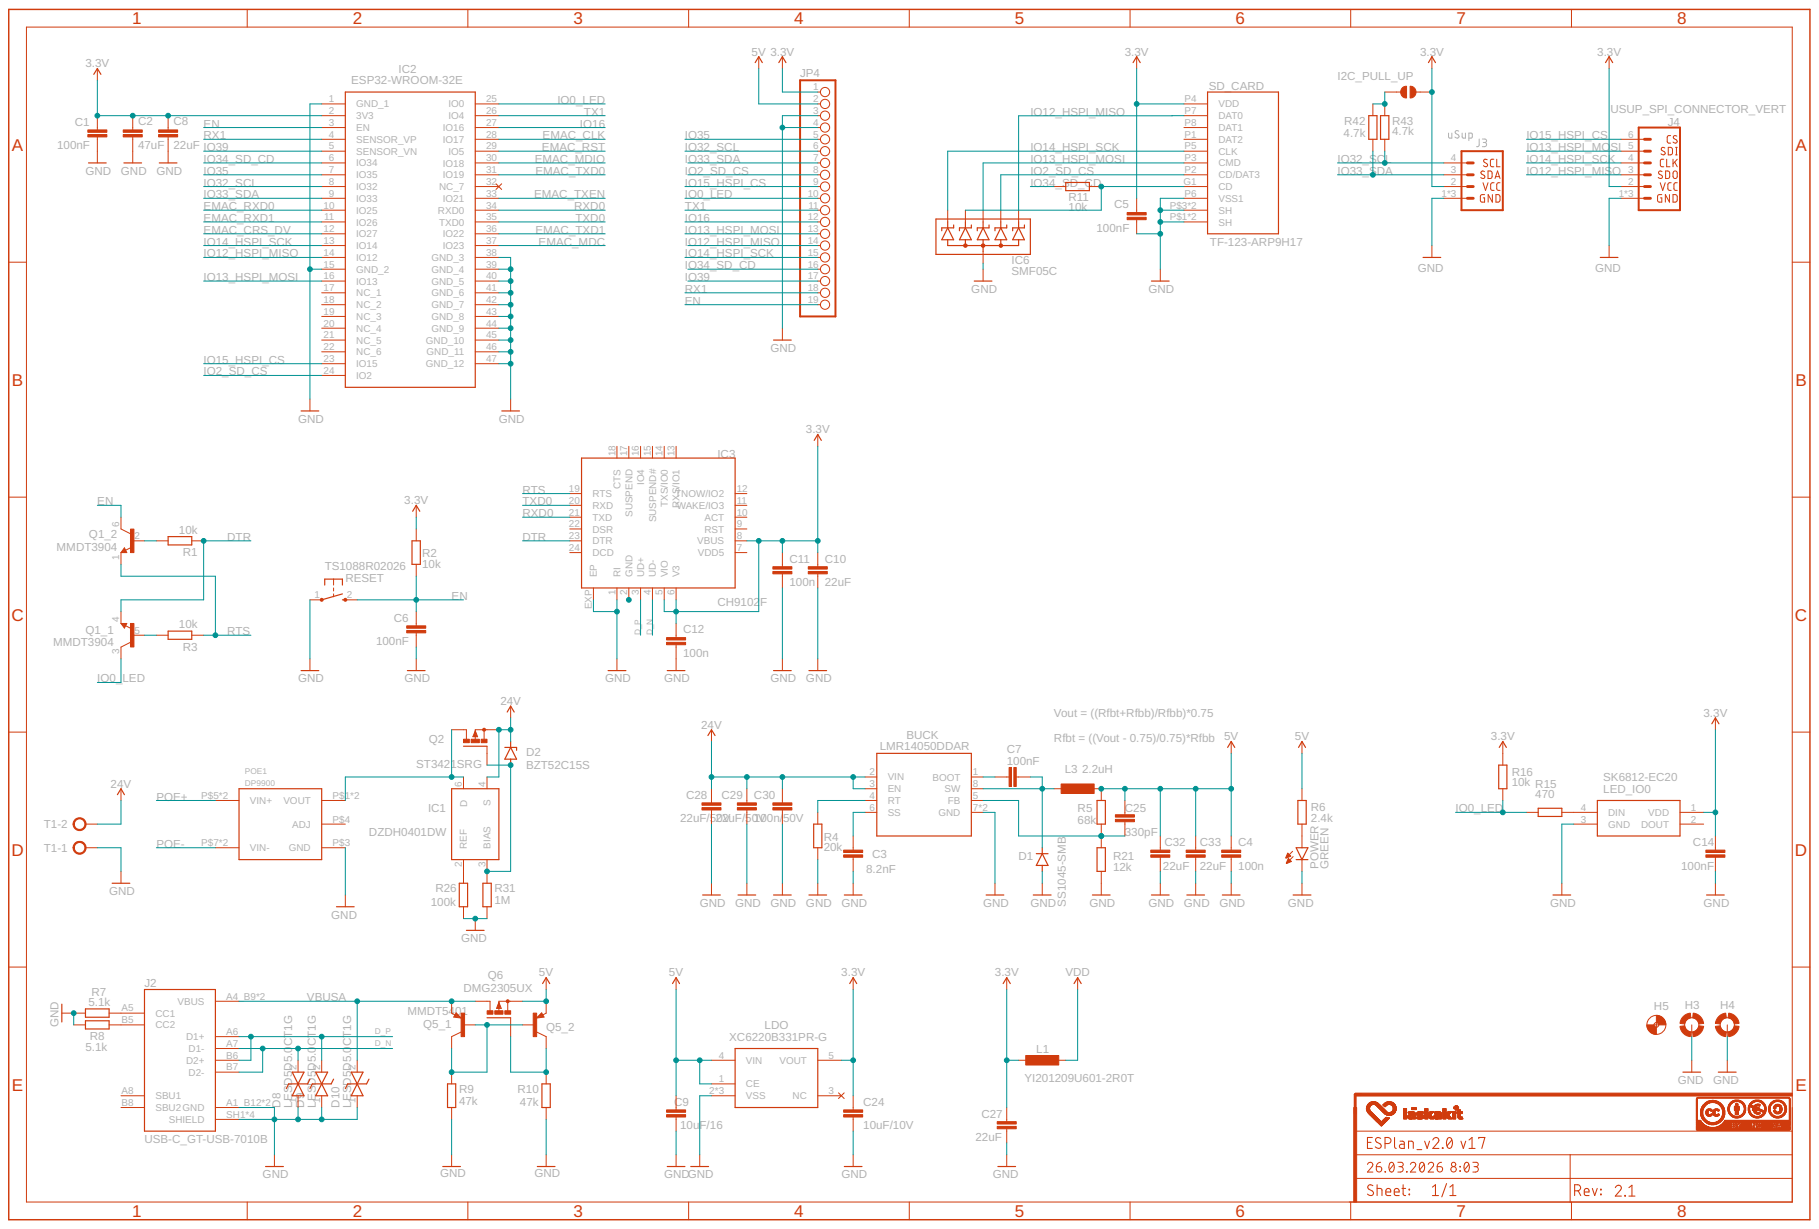
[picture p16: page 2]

Vout = ((Rfbt+Rfbb)/Rfbb)*0.75 Rfbt = ((Vout - 0.75)/0.75)*Rfbb

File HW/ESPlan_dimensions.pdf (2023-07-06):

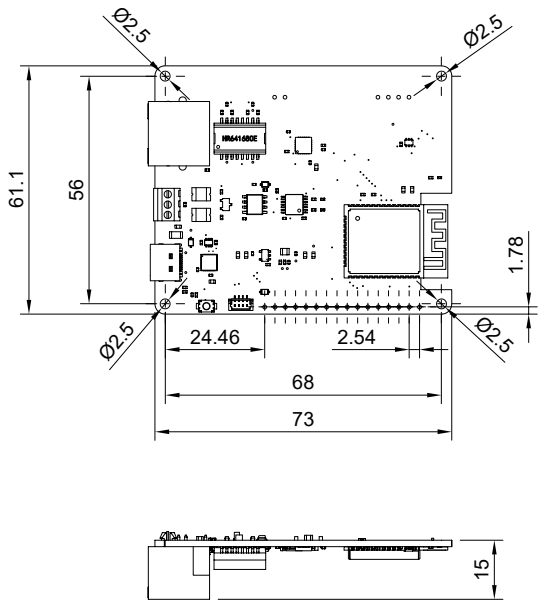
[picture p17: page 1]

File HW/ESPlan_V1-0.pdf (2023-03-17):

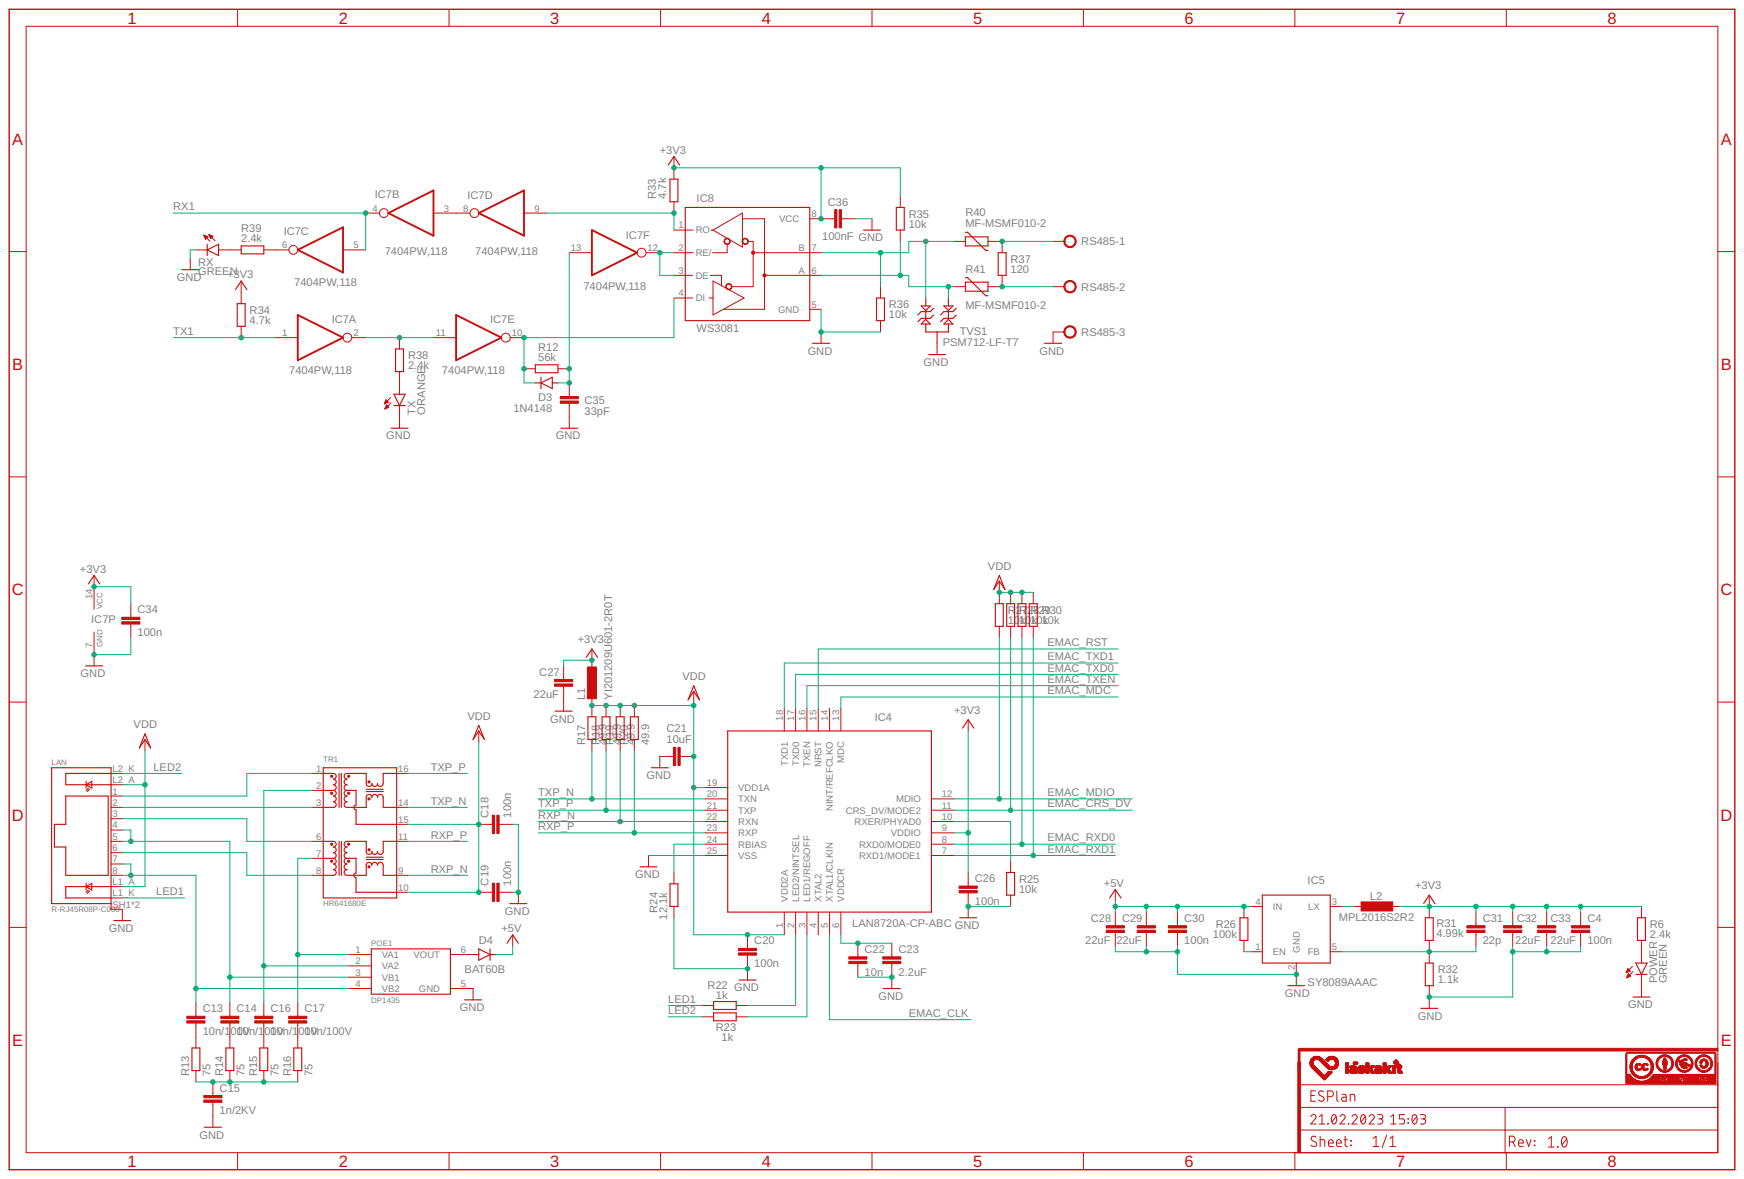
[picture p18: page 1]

EMAC_TXD1
EMAC_TXD0
EMAC_TXEN
EMAC_MDC

IC4 | EMAC_MDIO EMAC_CRS_DV EMAC_RXD0

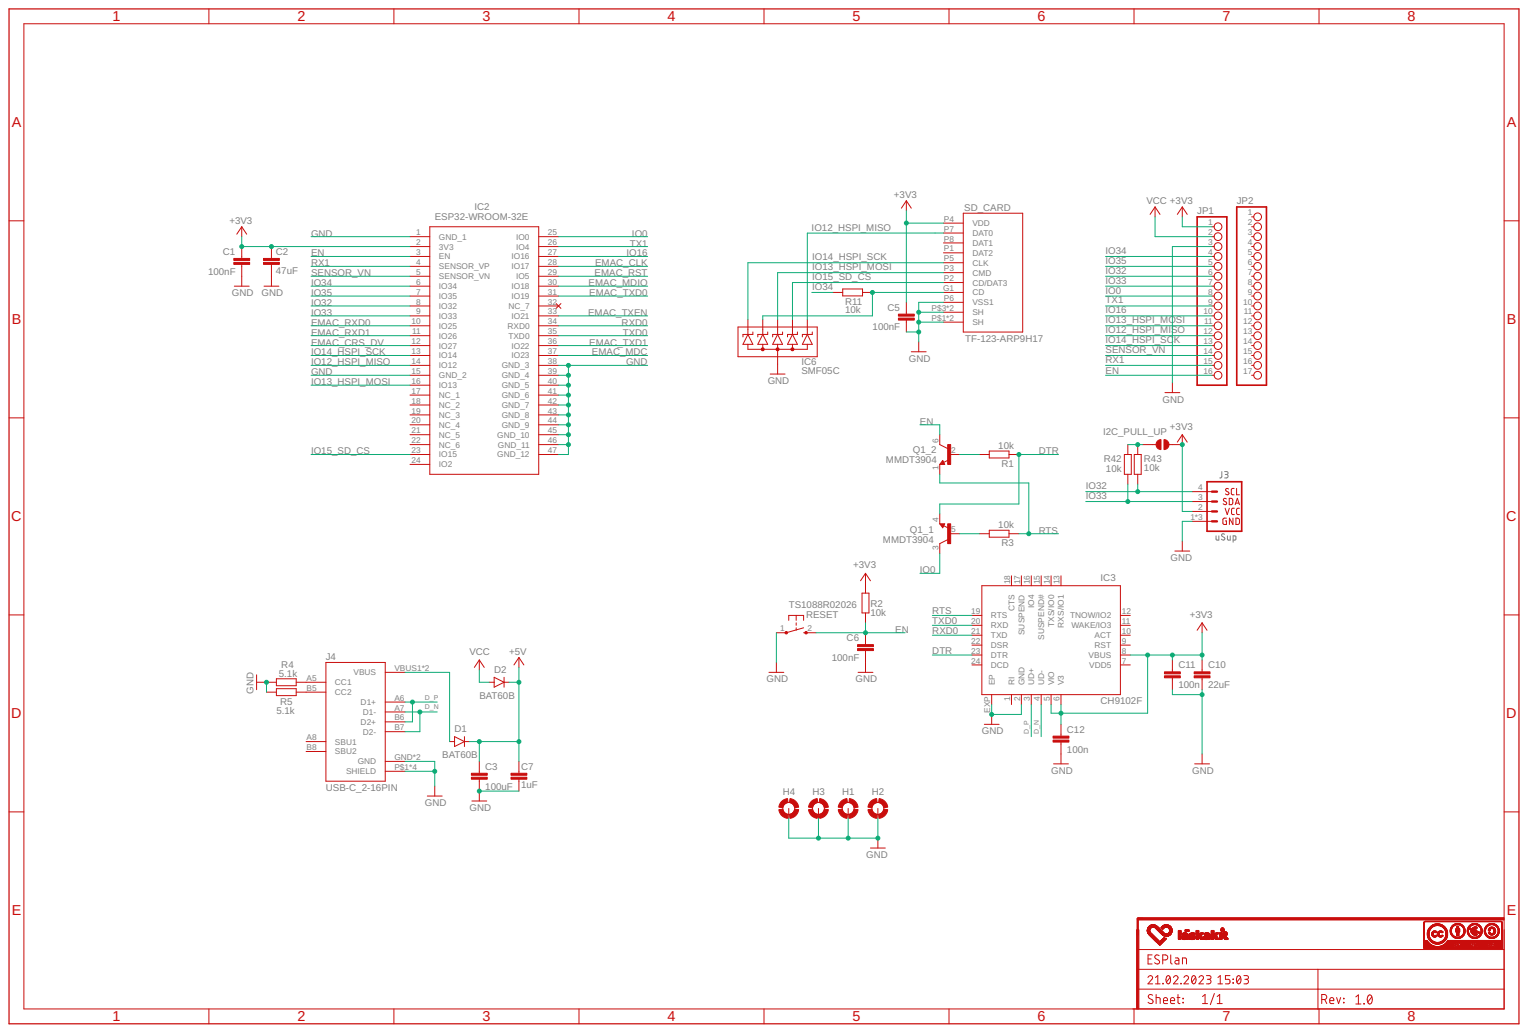
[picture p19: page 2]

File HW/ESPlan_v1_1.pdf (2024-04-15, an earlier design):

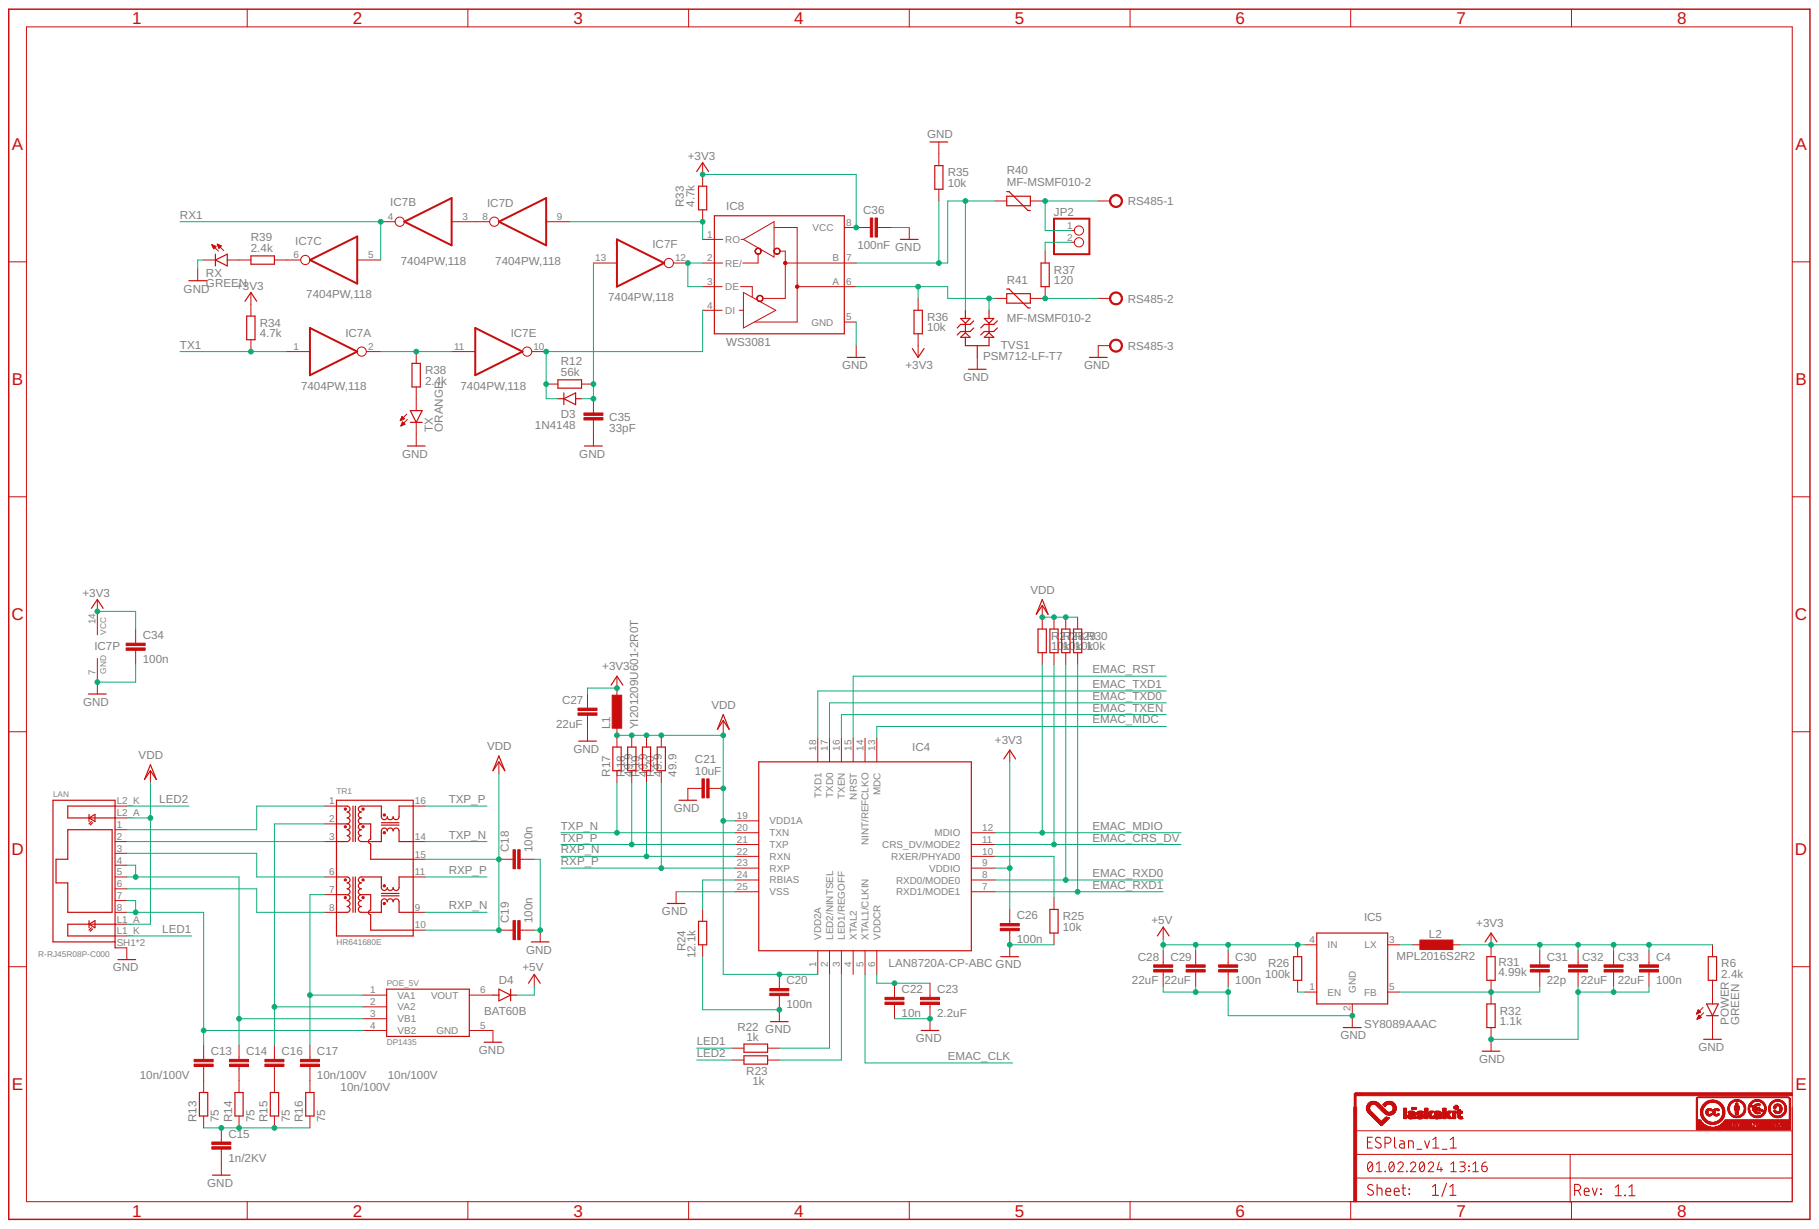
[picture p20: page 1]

EMAC_TXD1
EMAC_TXD0
EMAC_TXEN
EMAC_MDC

IC4 | EMAC_MDIO EMAC_CRS_DV EMAC_RXD0

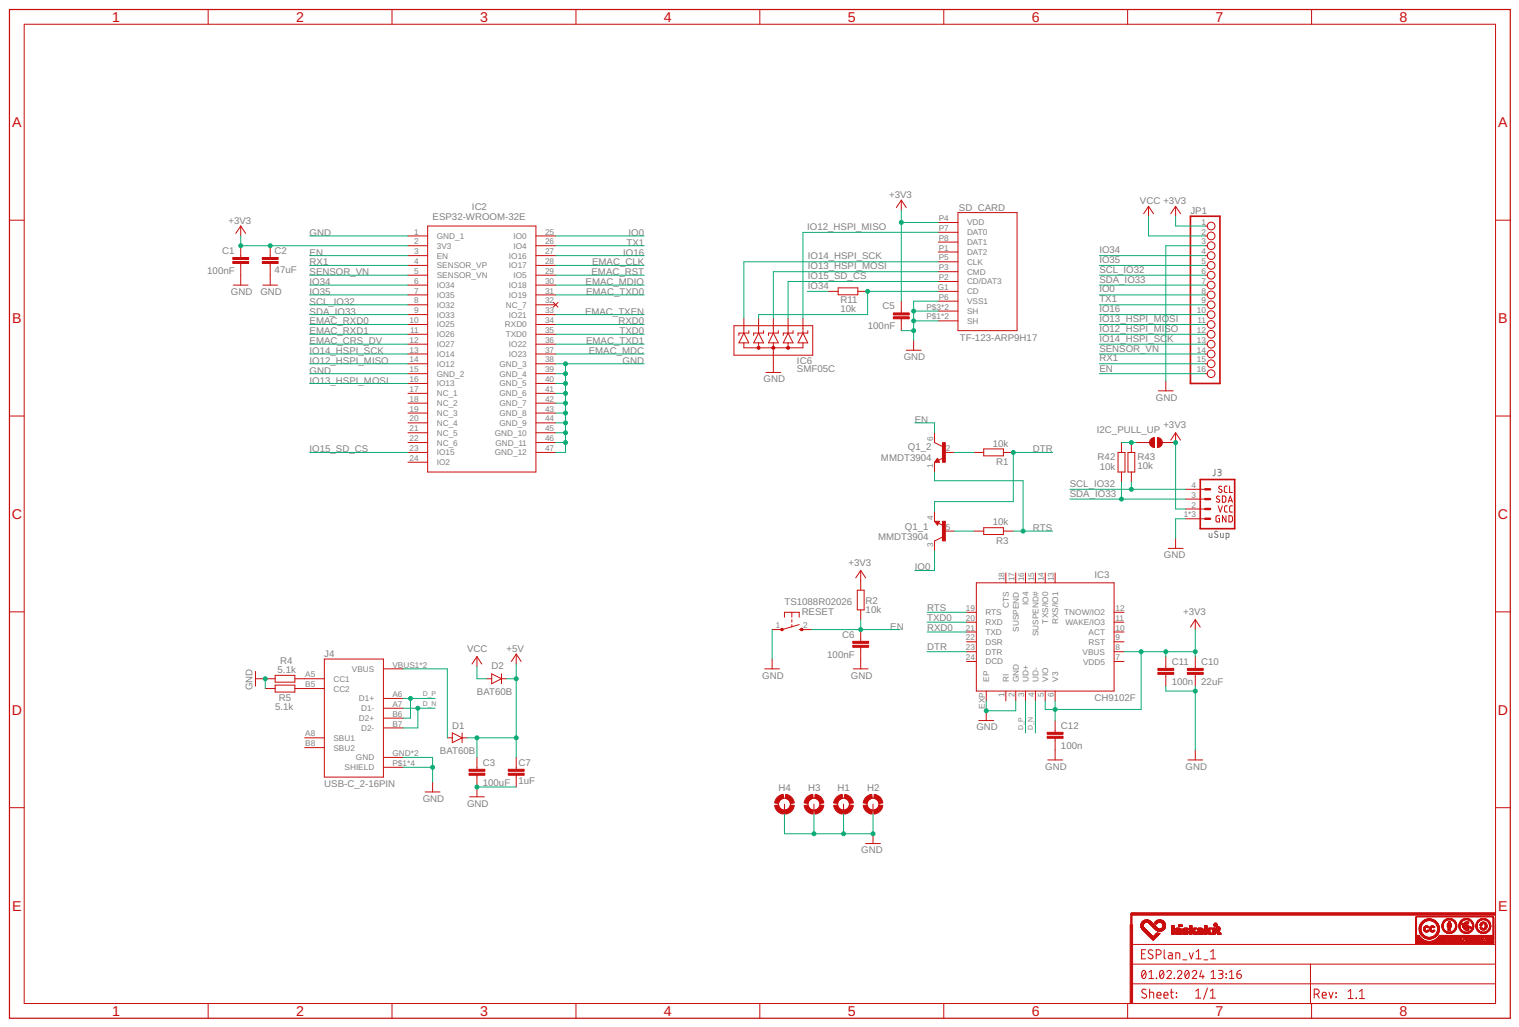
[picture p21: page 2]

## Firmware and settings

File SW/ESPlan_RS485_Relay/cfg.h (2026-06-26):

#ifndef RL_CFG_H
#define RL_CFG_H
/*
 * cfg.h – Konfigurace HW a datove struktury
 *
 * Zarizeni: 8 / 16-kanalovy RS485 rele modul (Modbus-RTU)
 *           https://www.laskakit.cz/8-kanalu-12v-rele-modul-250vac-10a--rs485--din/
 *
 * Protokol (datasheet 8ch_rele_rs485_protocols.pdf):
 *   FC 0x06 (Write Single Register), 8N1
 *   Adresa: 0x00-0x2F (0-47) – nastavena DIP prepinaci A0-A5 (HW)
 *   Baudrate: 9600 / 2400 / 4800 / 19200 (vychozi 9600, nastavi se M1/M2 pady)
 *
 *   Jednotlivy kanal (reg 0x0001 .. 0x000N):
 *     val_hi = funkce, val_lo = parametr/delay
 *
 *     0x0100   Open       (sepne)
 *     0x0200   Close      (rozepne)
 *     0x0300   Toggle     (self-locking)
 *     0x0400   Latch      (inter-locking; jen tento kanal ON, ostatni OFF)
 *     0x0500   Momentary  (non-locking, 1s puls)
 *     0x06xx   Delay XX s (xx = delka v sekundach 0x00..0xFF)
 *
 *   Vsechny kanaly (reg 0x0000):
 *     0x0700   All ON
 *     0x0800   All OFF
 *
 *   Cteni stavu (FC 0x03):
 *     reg 0x0001 .. 0x000N, vrati 0x0001 (ON) / 0x0000 (OFF)
 *
 *   Adresa zarizeni se NEMENI Modbusem – nastavi DIP prepinacem!
 */

#include <Arduino.h>
#include <Preferences.h>

// ─── ETH (LAN8720 na ESPlan) ──────────────────────────────────────────────────
#define ETH_PHY_TYPE    ETH_PHY_LAN8720
#define ETH_PHY_ADDR    0
#define ETH_PHY_MDC     23
#define ETH_PHY_MDIO    18
#define ETH_PHY_POWER   -1
#define ETH_CLK_MODE    ETH_CLOCK_GPIO17_OUT

// ─── RS485 / UART ─────────────────────────────────────────────────────────────
#define PIN_RS485_RX    36
#define PIN_RS485_TX    4

// ─── Modbus vychozi hodnoty ───────────────────────────────────────────────────
#define DEFAULT_MODBUS_ADDR     1
#define DEFAULT_BAUD_RATE       9600
#define DEFAULT_CHANNEL_COUNT   8        // 8 nebo 16
#define MAX_CHANNEL_COUNT       16
#define MODBUS_ADDR_MIN         0
#define MODBUS_ADDR_MAX         47       // 0x2F dle datasheetu (DIP A0-A5)

// ─── Registry rele modulu ────────────────────────────────────────────────────
#define REG_ALL_CHANNELS    0x0000
#define REG_CHANNEL_BASE    0x0001       // reg 0x0001 = ch1, az 0x0010 = ch16

// ─── Funkcni kody (val_hi) ───────────────────────────────────────────────────
#define FN_OPEN          0x01
#define FN_CLOSE         0x02
#define FN_TOGGLE        0x03
#define FN_LATCH         0x04
#define FN_MOMENTARY     0x05
#define FN_DELAY         0x06     // val_lo = delka v s (0-255)
#define FN_ALL_ON        0x07     // jen s reg 0x0000
#define FN_ALL_OFF       0x08     // jen s reg 0x0000

// helper na slozeni val pole pro Modbus zapis
inline uint16_t makeVal(uint8_t fn, uint8_t param = 0) {
  return ((uint16_t)fn << 8) | param;
}

// ─── Stav rele modulu ────────────────────────────────────────────────────────
struct RelayState {
  bool     channels[MAX_CHANNEL_COUNT] = { false };  // SW shadow (true = ON)
  uint32_t lastUpdateMs                = 0;
  uint32_t lastCmdMs                   = 0;
  bool     commError                   = false;
  String   errorMsg                    = "";
  String   lastAction                  = "";   // pro UI
};

// ─── Konfigurace (uklada se do NVS) ──────────────────────────────────────────
struct RelayConfig {
  uint8_t  modbusAddr    = DEFAULT_MODBUS_ADDR;
  uint32_t baudRate      = DEFAULT_BAUD_RATE;
  uint8_t  channelCount  = DEFAULT_CHANNEL_COUNT;   // 8 nebo 16
  uint8_t  defaultDelay  = 10;                      // pro tlacitko Delay (sekundy)

  // Nazvy kanalu (max 15 znaku + \0)
  char     names[MAX_CHANNEL_COUNT][16] = {
    "Rele 1",  "Rele 2",  "Rele 3",  "Rele 4",
    "Rele 5",  "Rele 6",  "Rele 7",  "Rele 8",
    "Rele 9",  "Rele 10", "Rele 11", "Rele 12",
    "Rele 13", "Rele 14", "Rele 15", "Rele 16"
  };
};

// ─── NVS load / save ─────────────────────────────────────────────────────────
inline void loadConfig(Preferences &p, RelayConfig &c) {
  c.modbusAddr   = p.getUChar("mbAddr",   DEFAULT_MODBUS_ADDR);
  c.baudRate     = p.getUInt ("baud",     DEFAULT_BAUD_RATE);
  c.channelCount = p.getUChar("chCount",  DEFAULT_CHANNEL_COUNT);
  if (c.channelCount != 8 && c.channelCount != 16) c.channelCount = 8;
  c.defaultDelay = p.getUChar("defDelay", 10);

  for (uint8_t i = 0; i < MAX_CHANNEL_COUNT; i++) {
    char key[8];
    snprintf(key, sizeof(key), "n%u", i);
    String def = String("Rele ") + (i + 1);
    String v   = p.getString(key, def);
    strncpy(c.names[i], v.c_str(), 15);
    c.names[i][15] = 0;
  }
}

inline void saveConfig(Preferences &p, const RelayConfig &c) {
  p.putUChar("mbAddr",   c.modbusAddr);
  p.putUInt ("baud",     c.baudRate);
  p.putUChar("chCount",  c.channelCount);
  p.putUChar("defDelay", c.defaultDelay);
  for (uint8_t i = 0; i < MAX_CHANNEL_COUNT; i++) {
    char key[8];
    snprintf(key, sizeof(key), "n%u", i);
    p.putString(key, c.names[i]);
  }
}

#endif // RL_CFG_H

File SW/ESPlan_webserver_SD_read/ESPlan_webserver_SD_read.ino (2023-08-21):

/* Webserver reads from SD text file test for LaskaKit ESPlan
 * After boot connect to http://esplan.local or to IP adress of ESP32 (for example 192.168.0.98)
 * Email:podpora@laskakit.cz
 * Web:laskakit.cz
 */

#include <Arduino.h>
#include <WiFi.h>
#include <ETH.h>
#include <WebServer.h>
#include <ESPmDNS.h>
#include <SPI.h>
#include <SD.h>
#include <FS.h>
#include "page.h"

const char *host = "esplan"; // Connect to http://esplan.local

// SD card defines
#define SCK 14
#define MISO 12
#define MOSI 13
#define CS 15
SPIClass spi = SPIClass(HSPI);

// Set web server port number to 80
WebServer server(80);

// LAN8720A parameters
#define ETH_POWER_PIN -1
#define ETH_ADDR 0
#define ETH_MDC_PIN 23
#define ETH_MDIO_PIN 18
#define ETH_NRST_PIN 5

static bool eth_connected = false;

void WiFiEvent(WiFiEvent_t event)
{
    switch (event)
    {
    case ARDUINO_EVENT_ETH_START:
        Serial.println("ETH Started");
        // set eth hostname here
        ETH.setHostname("esplan");
        break;
    case ARDUINO_EVENT_ETH_CONNECTED:
        Serial.println("ETH Connected");
        break;
    case ARDUINO_EVENT_ETH_GOT_IP:
        Serial.print("ETH MAC: ");
        Serial.print(ETH.macAddress());
        Serial.print(", IPv4: ");
        Serial.print(ETH.localIP());
        if (ETH.fullDuplex())
        {
            Serial.print(", FULL_DUPLEX");
        }
        Serial.print(", ");
        Serial.print(ETH.linkSpeed());
        Serial.println("Mbps");
        eth_connected = true;
        break;
    case ARDUINO_EVENT_ETH_DISCONNECTED:
        Serial.println("ETH Disconnected");
        eth_connected = false;
        break;
    case ARDUINO_EVENT_ETH_STOP:
        Serial.println("ETH Stopped");
        eth_connected = false;
        break;
    default:
        break;
    }
}

void readFile(fs::FS &fs, const char *path)
{
    char text[100] = {0};
    char out[100] = {0};
    uint8_t i = 0;
    Serial.printf("Reading file: %s\n", path);

    File file = fs.open(path);
    if (!file)
    {
        Serial.println("Failed to open file for reading");
        return;
    }

    Serial.print("Read from file: ");
    while (file.available())
    {
        text[i] = file.read();
        if (text[i++] == '\n')
        {
            Serial.print(text);
            sprintf(out, "<p>%s</p>", text);
            server.sendContent(out);
            memset(text, 0, 99 * sizeof(*text));
            memset(out, 0, 99 * sizeof(*out));
            i = 0;
        }
    }
    file.close();
}

void writeFile(fs::FS &fs, const char *path, const char *message)
{
    Serial.printf("Writing file: %s\n", path);

    File file = fs.open(path, FILE_WRITE);
    if (!file)
    {
        Serial.println("Failed to open file for writing");
        return;
    }
    if (file.print(message))
    {
        Serial.println("File written");
    }
    else
    {
        Serial.println("Write failed");
    }
    file.close();
}

uint8_t appendFile(fs::FS &fs, const char *path, const char *message)
{
    Serial.printf("Appending to file: %s\n", path);

    File file = fs.open(path, FILE_APPEND);
    if (!file)
    {
        Serial.println("Failed to open file for appending");
        return 1;
    }
    if (file.print(message))
    {
        Serial.println("Message appended");
        file.close();
        return 0;
    }
    else
    {
        Serial.println("Append failed");
        file.close();
        return 1;
    }
}

void handleRoot()
{
    server.setContentLength(CONTENT_LENGTH_UNKNOWN);
    server.send_P(200, "text/html", index_html);
    spi.begin(SCK, MISO, MOSI, CS);
    if (SD.begin(CS, spi))
    {
        Serial.println("SD Card initialized.");
        readFile(SD, "/output.txt");
    }
    else
    {
        server.sendContent("<p style= \"color:rgb(255, 0, 0);\">SD card not found!</p>");
    }
    server.sendContent("</body>");
    server.sendContent(""); // This ends sending
    SD.end();
    spi.end();
}

void handleSubmit()
{
    char text[100] = {0};
    spi.begin(SCK, MISO, MOSI, CS);
    if (SD.begin(CS, spi))
    {
        Serial.println("SD Card initialized.");
        sprintf(text, "%s\n", server.arg(0).c_str());
        Serial.println(server.arg(0));
        if (appendFile(SD, "/output.txt", text))
        {
            writeFile(SD, "/output.txt", text);
        }
    }
    SD.end();
    spi.end();
    handleRoot();
}

void handleNotFound()
{
    String message = "Error\n\n";
    message += "URI: ";
    message += server.uri();
    message += "\nMethod: ";
    message += (server.method() == HTTP_GET) ? "GET" : "POST";
    message += "\nArguments: ";
    message += server.args();
    message += "\n";
    for (uint8_t i = 0; i < server.args(); i++)
    {
        message += " " + server.argName(i) + ": " + server.arg(i) + "\n";
    }
    server.send(404, "text/plain", message);
}

void DNS_setup()
{
    if (MDNS.begin(host))
    {
        MDNS.addService("http", "tcp", 80);
        Serial.println("MDNS responder started");
        Serial.print("You can now connect to http://");
        Serial.print(host);
        Serial.println(".local");
    }
}

void setup()
{
    Serial.begin(115200);
    // For reseting LAN8720A
    pinMode(ETH_NRST_PIN, OUTPUT);
    digitalWrite(ETH_NRST_PIN, LOW);
    delay(500);
    digitalWrite(ETH_NRST_PIN, HIGH);

    WiFi.onEvent(WiFiEvent);
    ETH.begin(ETH_ADDR, ETH_POWER_PIN, ETH_MDC_PIN, ETH_MDIO_PIN, ETH_PHY_LAN8720, ETH_CLOCK_GPIO17_OUT);

    DNS_setup();

    server.on("/", handleRoot); // Main page

    server.on("/get", handleSubmit); // Function done on GET request

    server.onNotFound(handleNotFound); // Function done when hangle is not found

    server.begin();
    Serial.println("HTTP server started");
}

void loop()
{
    if (eth_connected)
    {
        server.handleClient();
    }
    delay(2); // allow the cpu to switch to other tasks
}

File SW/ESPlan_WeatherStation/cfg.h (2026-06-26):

#ifndef WS_CFG_H
#define WS_CFG_H
/*
 * cfg.h – Konfigurace hardwaru a datové struktury
 *
 * POZOR: Konfigurace HW pinů je pevná (nelze měnit přes web).
 *        Přes webové rozhraní lze měnit pouze komunikační parametry
 *        a kalibrační registry snímače.
 */

#include <Arduino.h>
#include <Preferences.h>

// ─── ETH (LAN8720 na ESPlan) ──────────────────────────────────────────────────
#define ETH_PHY_TYPE    ETH_PHY_LAN8720
#define ETH_PHY_ADDR    0
#define ETH_PHY_MDC     23
#define ETH_PHY_MDIO    18
#define ETH_PHY_POWER   -1
#define ETH_CLK_MODE    ETH_CLOCK_GPIO17_OUT

// ─── RS485 / UART ─────────────────────────────────────────────────────────────
#define PIN_RS485_RX    36
#define PIN_RS485_TX    4
// DE pin je řízen hardwarově – nepotřebujeme softwarové ovládání

// ─── Modbus výchozí hodnoty ───────────────────────────────────────────────────
#define DEFAULT_MODBUS_ADDR     1
#define DEFAULT_BAUD_RATE       4800
#define DEFAULT_POLL_INTERVAL   5      // sekundy

// ─── Modbus registry snímače (RS-FSXCS-N01-*) ────────────────────────────────
// Čtecí registry (FC03 / FC04), base address 500 (0x01F4)
#define REG_WIND_SPEED      500
#define REG_WIND_FORCE      501
#define REG_WIND_DIR_8      502
#define REG_WIND_DIR_360    503
#define REG_HUMIDITY        504
#define REG_TEMPERATURE     505
#define REG_NOISE           506
#define REG_PM25_CO2        507
#define REG_PM10_CO2        508
#define REG_PRESSURE        509
#define REG_LUX_HIGH        510
#define REG_LUX_LOW         511
#define REG_LUX_100         512
#define REG_RAINFALL        513
#define REG_COMPASS         514
#define REG_SOLAR           515

// Kalibrační / konfigurační registry (FC06)
#define REG_WIND_DIR_OFFSET 0x6000
#define REG_WIND_ZERO       0x6001
#define REG_RAIN_ZERO       0x6002
#define REG_RAIN_SENS       0x6003

// ─── Flags přítomnosti senzorů ────────────────────────────────────────────────
struct SensorPresence {
  bool wind       = false;
  bool tempHum    = false;
  bool pressure   = false;
  bool noise      = false;
  bool pm25       = false;
  bool pm10       = false;
  bool co2        = false;
  bool light      = false;
  bool rainfall   = false;
  bool compass    = false;
  bool solar      = false;
};

// ─── Naměřené hodnoty ─────────────────────────────────────────────────────────
struct SensorData {
  SensorPresence  present;

  float    windSpeed   = 0.0f;
  uint16_t windForce   = 0;
  uint8_t  windDir8    = 0;
  uint16_t windDir360  = 0;

  float    temperature = 0.0f;
  float    humidity    = 0.0f;
  float    pressure    = 0.0f;
  float    noise       = 0.0f;

  uint16_t pm25        = 0;
  uint16_t pm10        = 0;
  uint16_t co2         = 0;

  uint32_t luxFull     = 0;
  uint32_t lux100      = 0;

  float    rainfall    = 0.0f;
  float    compass     = 0.0f;
  uint16_t solar       = 0;

  uint32_t lastUpdateMs = 0;
  bool     commError    = false;
  String   errorMsg     = "";
};

// ─── Konfigurace snímače (ukládá se do NVS) ───────────────────────────────────
struct SensorConfig {
  uint8_t  modbusAddr    = DEFAULT_MODBUS_ADDR;
  uint32_t baudRate      = DEFAULT_BAUD_RATE;
  uint8_t  pollInterval  = DEFAULT_POLL_INTERVAL;

  uint8_t  windDirOffset   = 0;
  uint8_t  rainSensitivity = 0x11;
  uint8_t  slot507Mode     = 0;  // 0=auto, 1=PM, 2=CO2
  uint8_t  slot508Mode     = 0;
};

// ─── NVS load / save ──────────────────────────────────────────────────────────
inline void loadConfig(Preferences &p, SensorConfig &c) {
  c.modbusAddr      = p.getUChar("mbAddr",   DEFAULT_MODBUS_ADDR);
  c.baudRate        = p.getUInt ("baud",     DEFAULT_BAUD_RATE);
  c.pollInterval    = p.getUChar("poll",     DEFAULT_POLL_INTERVAL);
  c.windDirOffset   = p.getUChar("wdOffset", 0);
  c.rainSensitivity = p.getUChar("rainSens", 0x11);
  c.slot507Mode     = p.getUChar("slot507",  0);
  c.slot508Mode     = p.getUChar("slot508",  0);
}

inline void saveConfig(Preferences &p, const SensorConfig &c) {
  p.putUChar("mbAddr",   c.modbusAddr);
  p.putUInt ("baud",     c.baudRate);
  p.putUChar("poll",     c.pollInterval);
  p.putUChar("wdOffset", c.windDirOffset);
  p.putUChar("rainSens", c.rainSensitivity);
  p.putUChar("slot507",  c.slot507Mode);
  p.putUChar("slot508",  c.slot508Mode);
}

inline const char* windDir8Name(uint8_t d) {
  static const char* names[] = {"N","NE","E","SE","S","SW","W","NW"};
  return (d < 8) ? names[d] : "?";
}

#endif // WS_CFG_H

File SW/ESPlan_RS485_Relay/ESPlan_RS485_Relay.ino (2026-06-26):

/*
 * ESPlan_RS485_Relay.ino
 * 8 / 16-kanalovy RS485 rele modul (Modbus-RTU)
 *
 * Hardware : LaskaKit ESPlan (ESP32 + LAN8720)
 * Modul    : 8-ch / 16-ch 12V rele 250VAC/10A RS485 DIN
 *            https://www.laskakit.cz/8-kanalu-12v-rele-modul-250vac-10a--rs485--din/
 *
 * Soubory projektu:
 *   cfg.h           - HW konstanty, registry, datove struktury
 *   mb_client.h/cpp - Modbus RTU klient (FC03, FC06)
 *   relay.h/cpp     - Ovladani rele (set/toggle/latch/momentary/delay/all/read)
 *   i18n_str.h      - Preklady CZ / EN
 *   ws_server.h/cpp - HTTP webserver
 *
 * Modbus protokol (datasheet 8ch_rele_rs485_protocols.pdf):
 *   FC 0x06 (Write Single Register), 8N1
 *   Adresa modulu se nastavuje DIP prepinaci A0-A5 (rozsah 0-47)
 *   Baudrate (HW pady M1/M2): 9600 (default) / 2400 / 4800 / 19200
 *
 *   reg 0x0001..0x0010  - rele 1..16 (jednotlive kanaly)
 *     val 0x0100 = Open (sepne)
 *     val 0x0200 = Close (rozepne)
 *     val 0x0300 = Toggle (self-locking)
 *     val 0x0400 = Latch (inter-locking)
 *     val 0x0500 = Momentary (1s puls)
 *     val 0x06xx = Delay xx s (0-255)
 *   reg 0x0000  - vsechny kanaly
 *     val 0x0700 = Vsechny ON
 *     val 0x0800 = Vsechny OFF
 *
 *   FC 0x03 cteni stavu: reg 0x0001..0x0010, vrati 0x0001=ON / 0x0000=OFF
 */

#include <Arduino.h>
#include <WiFi.h>
#include <ETH.h>
#include <Preferences.h>

#include "cfg.h"
#include "mb_client.h"
#include "relay.h"
#include "ws_server.h"

// ─── Globalni objekty ─────────────────────────────────────────────────────────
Preferences   prefs;
RelayState    relayState;
RelayConfig   relayCfg;
ModbusClient  modbusClient;

static bool     ethGotIP   = false;
static uint32_t lastReadMs = 0;
static const uint32_t READ_INTERVAL_MS = 5000;  // 5s pravidelna sync z modulu

// ─── ETH udalosti ─────────────────────────────────────────────────────────────
void onEthEvent(WiFiEvent_t event) {
  switch (event) {
    case ARDUINO_EVENT_ETH_START:
      Serial.println(F("[ETH] Inicializace..."));
      ETH.setHostname("espplan-relay");
      break;
    case ARDUINO_EVENT_ETH_CONNECTED:
      Serial.println(F("[ETH] Pripojen (fyzicka vrstva)"));
      break;
    case ARDUINO_EVENT_ETH_GOT_IP:
      Serial.print(F("[ETH] IP: "));
      Serial.println(ETH.localIP());
      ethGotIP = true;
      break;
    case ARDUINO_EVENT_ETH_DISCONNECTED:
      Serial.println(F("[ETH] Odpojeno"));
      ethGotIP = false;
      break;
    case ARDUINO_EVENT_ETH_STOP:
      Serial.println(F("[ETH] Zastaveno"));
      break;
    default:
      break;
  }
}

// ─── Setup ────────────────────────────────────────────────────────────────────
void setup() {
  Serial.begin(115200);
  delay(500);
  Serial.println(F("\n=== ESPlan RS485 Relay 8/16ch ==="));
  Serial.println(F("    LaskaKit 8/16-ch Modbus-RTU "));
  Serial.println(F("============================="));

  // Nacteni konfigurace z NVS
  prefs.begin("rs485rel", true);
  loadConfig(prefs, relayCfg);
  prefs.end();

  Serial.printf("[CFG] Modbus addr=%d baud=%d\n",
                relayCfg.modbusAddr,
                relayCfg.baudRate);

  // RS485 / Modbus
  modbusClient.begin(relayCfg.baudRate, relayCfg.modbusAddr);

  // ETH
  WiFi.onEvent(onEthEvent);
  ETH.begin(ETH_PHY_TYPE,
            ETH_PHY_ADDR,
            ETH_PHY_MDC,
            ETH_PHY_MDIO,
            ETH_PHY_POWER,
            ETH_CLK_MODE);

  uint32_t t0 = millis();
  while (!ethGotIP && (millis() - t0 < 10000)) {
    delay(100);
  }
  if (!ethGotIP) {
    Serial.println(F("[ETH] VAROVANI: IP neziskano - web nebude dostupny!"));
  }

  // Webserver
  webServerBegin(relayState, relayCfg, prefs, modbusClient);

  // Pokus o nacteni stavu (pokud modul podporuje FC03)
  Serial.println(F("[REL] Pokus o sync stavu z modulu..."));
  relayReadAll(modbusClient, relayState, relayCfg);

  Serial.println(F("[SYS] Inicializace dokoncena."));
}

// ─── Loop ─────────────────────────────────────────────────────────────────────
void loop() {
  webServerHandle();

  // Periodicky pokus o aktualizaci stavu (volitelne)
  uint32_t now = millis();
  if (now - lastReadMs >= READ_INTERVAL_MS) {
    lastReadMs = now;
    relayReadAll(modbusClient, relayState, relayCfg);
  }

  delay(5);
}

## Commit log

2023-02-10 new ver
    [ESPlan_bottom_cpl.csv, ESPlan_cpl.csv]
2023-05-08 new data
    [ESPlan_cpl.csv]
2023-05-18 Create ESPlan v1.dxf
    [ESPlan v1.dxf]
2023-08-24 Update example to ETH and Arduino IDE
2023-11-21 added power_pin
2024-01-16 fixing holes added
    [ESPlan_case.3mf]
2024-04-15 update to 1.1
    [ESPlan_bom.csv, ESPlan_v1_1_top_bom.csv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]
2026-03-06 new test data
    [ESPlan v1.dxf, ESPlan_v1_1_top_bom.csv, ESPlan_v2.0 v43_bom.csv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]
2026-06-08 moved, new data
    [ESPlan_v2.0 v43_bom.csv, ESPlan_v2_JLCPCB_BOM.csv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]
